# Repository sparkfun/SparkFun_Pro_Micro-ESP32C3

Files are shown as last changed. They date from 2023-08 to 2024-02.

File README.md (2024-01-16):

SparkFun Pro Micro ESP32-C3
========================================

SparkFun Pro Micro ESP32-C3 (https://www.sparkfun.com/products/23484)

[*SparkFun Pro Micro ESP32-C3 (DEV-23484)*](https://www.sparkfun.com/products/23484)

Don't be fooled by its miniature size; the SparkFun Pro Micro ESP32-C3 packs a punch. This micro marvel crams the powerful ESP32-C3, a single-core RISC-V powerhouse with 400KB of SRAM, into a compact 1.3in. x 0.7in. board. Clocking in at 160MHz, it's ready to tackle your projects quickly and efficiently.

Forget wires and soldering headaches – the Pro Micro ESP32-C3 embraces the simplicity of the Qwiic connector. Just plug and play any Qwiic sensor and watch your projects come alive with environmental data, motion detection, or whatever your imagination conjures. And stay connected, wherever you are, with built-in WiFi and Bluetooth® 5 (LE).

But the Pro Micro ESP32-C3 isn't just about small talk. Its 22 programmable GPIOs, accessible through handy castellated headers, unlock a multitude of possibilities. From tinkering with LEDs and servos to crafting intricate sensor networks, this tiny titan has the muscle to handle it all. And thanks to support for a range of protocols like ADC, SPI, UART, and I<sup>2</sup>C, the creative toolbox keeps expanding.

The Pro Micro ESP32-C3 taps into the power of Espressif's open-source ESP-IDF, a robust ecosystem brimming with libraries, tools, and a supportive community. Plus, you can leverage the familiar Arduino IDE for a smooth development experience.

So whether you're building a wearable masterpiece, a chatty IoT gadget, or a robotic friend, the SparkFun Pro Micro ESP32-C3 is your pint-sized partner in innovation. Grab one today and let your small-scale dreams take flight!

Repository Contents
-------------------

* **/Documentation** - Data sheets, additional product information
* **/Hardware** - Eagle design files (.brd, .sch)
* **/Production** - Production panel files (.brd)

Documentation
--------------
* **[Hookup Guide](https://docs.sparkfun.com/SparkFun_Pro_Micro-ESP32C3)** - Basic hookup guide for the SparkFun Pro Micro ESP32-C3

License Information
-------------------

This product is _**open source**_! 

Please review the LICENSE.md file for license information. 

If you have any questions or concerns on licensing, please contact technical support on our [SparkFun forums](https://forum.sparkfun.com/viewforum.php?f=152).

Distributed as-is; no warranty is given.

- Your friends at SparkFun.

_<COLLABORATION CREDIT>_

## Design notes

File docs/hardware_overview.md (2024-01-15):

---
icon: material/cog
---

## ESP32 C3 WiFi Module

The ESP32-C3 from Espressif is a single-core, 32-bit, RISC-V-based MCU with 400KB of SRAM, which is capable of running at 160MHz. It has integrated 2.4 GHz Wi-Fi and Bluetooth 5 (LE) with a long-range support. It has 22 programmable GPIOs with support for ADC, SPI, UART, I2C, I2S, RMT, TWAI, and PWM. More information is available in the [datasheet](Documents/esp32-c3-mini-1_datasheet_en.pdf). 

<figure markdown>
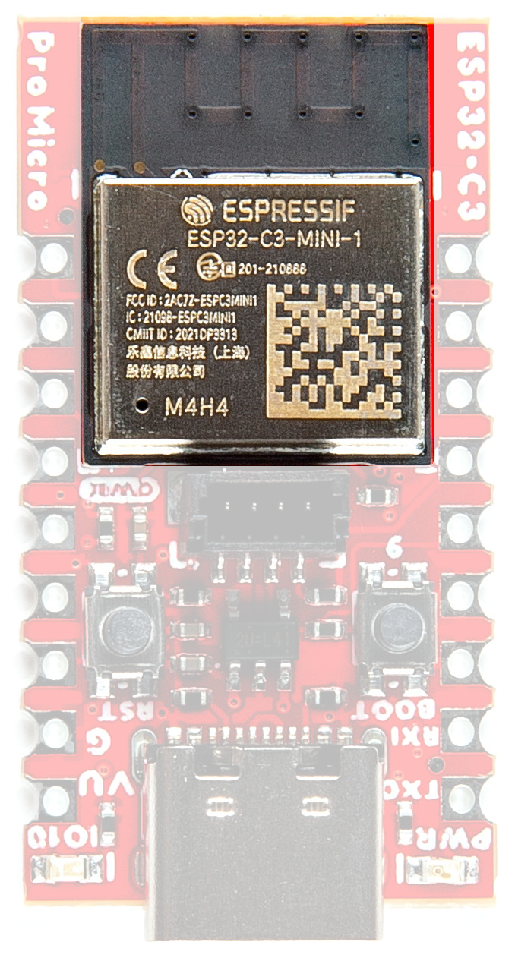
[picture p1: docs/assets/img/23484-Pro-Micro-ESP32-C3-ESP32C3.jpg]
ESP32 C3 WiFi Module

<figcaption markdown>ESP32 C3 WiFi Module</figcaption>
</figure>

## Voltage Regulator - RT9080

The RT9080 regulates voltage to the various components of the board. Maximum input voltage should be no more than <b>5.5V</b>. 

Current Max: 600mA

<figure markdown>
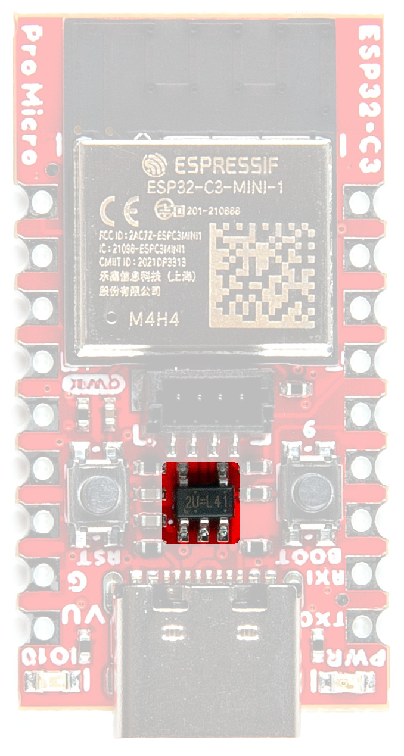
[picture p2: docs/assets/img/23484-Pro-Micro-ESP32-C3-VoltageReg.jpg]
Voltage Regulator - RT9080

<figcaption markdown>Voltage Regulator - RT9080</figcaption>
</figure>

## Qwiic Connector

The board includes a Qwiic connector for use with our vast array of Qwiic sensors. For users that need to solder directly to the board, the pins are also broken out on the edge PTH. The I<sup>2</sup>C data and clock lines are also tied to 2.2kΩ pull-up resistors.

<figure markdown>
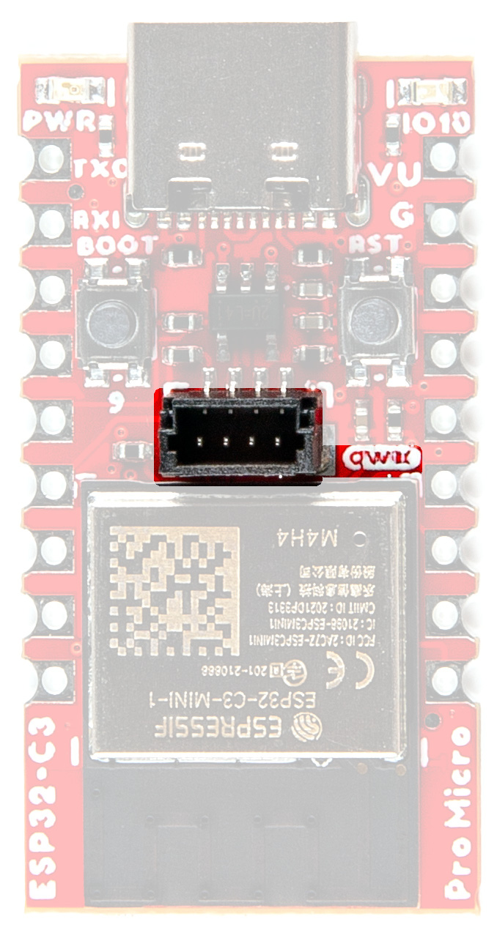
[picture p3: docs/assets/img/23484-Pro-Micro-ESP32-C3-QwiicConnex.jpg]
Qwiic Connector

<figcaption markdown>Qwiic Connector</figcaption>
</figure>

## JTAG 

While most users will utilize the USB connection for programming, the ESP32-C3 can also be programmed through its JTAG or SWD pins. This is useful for individuals developing and debugging firmware that would be flashed directly onto the module, such as in production for commercial applications. We recommend soldering a [2x5 Male Pin header](https://www.sparkfun.com/products/15362) for use. 

<figure markdown>
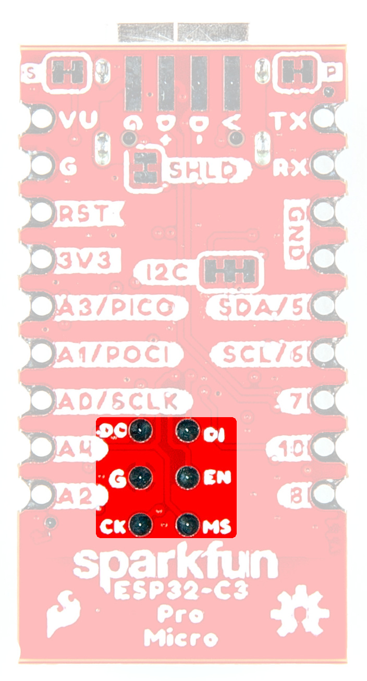
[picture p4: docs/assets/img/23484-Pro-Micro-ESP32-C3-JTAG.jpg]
ESP32 JTAG pads

<figcaption markdown>ESP32 JTAG pads</figcaption>
</figure>

## Castellated Headers

The castellated headers along either side of the board are useful for adding complex functionality like RF to a design, as well as being low profile and compact. If you've never worked with castellated headers, head on over to our [Castellated Mounting Holes Tutorial](https://learn.sparkfun.com/tutorials/how-to-solder-castellated-mounting-holes) for more information. 

<figure markdown>
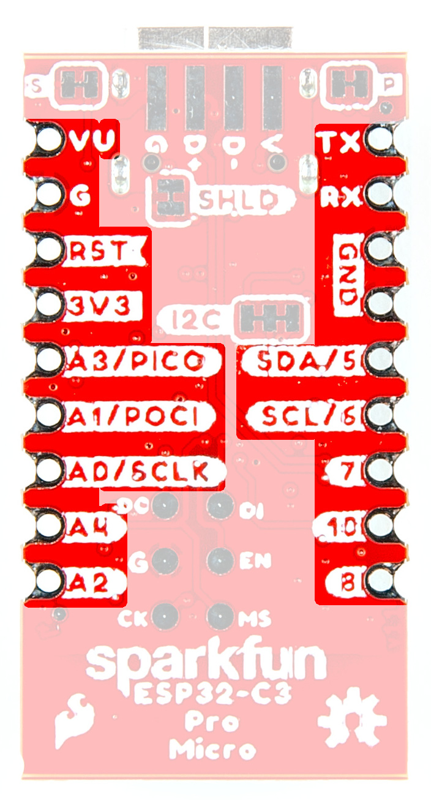
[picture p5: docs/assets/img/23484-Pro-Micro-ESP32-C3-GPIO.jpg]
ESP32 GPIO

<figcaption markdown>Castellated Headers</figcaption>
</figure>

## Buttons

There are two buttons on the board - Reset and Boot. The reset (RST) button allows users to reset the program running on the ESP32-C3 module without unplugging the board. The Boot Button allows the user to manually put the board into Bootloader Mode. To enter bootloader, hold the Boot button down when the ESP32 resets or powers on. 

<figure markdown>
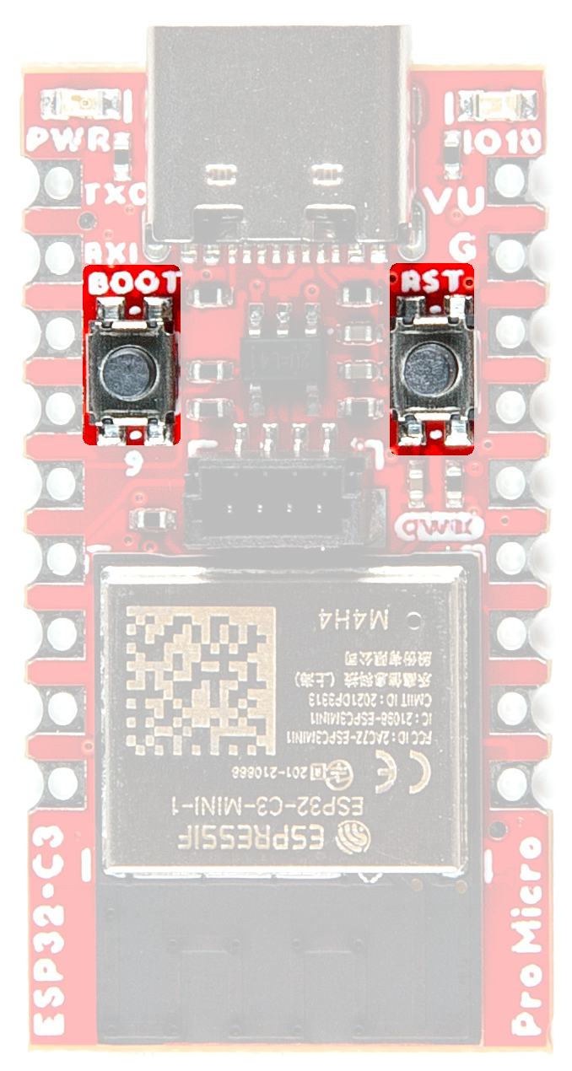
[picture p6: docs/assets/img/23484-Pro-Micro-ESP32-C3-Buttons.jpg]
ESP32 Boot and Reset Buttons

<figcaption markdown>Boot and Reset Buttons</figcaption>
</figure>

## LEDs

Two LEDs - Power(Red) and STAT(Blue) - show the user that power has been appropriately supplied to the board and the status of the data transfer. 

<figure markdown>
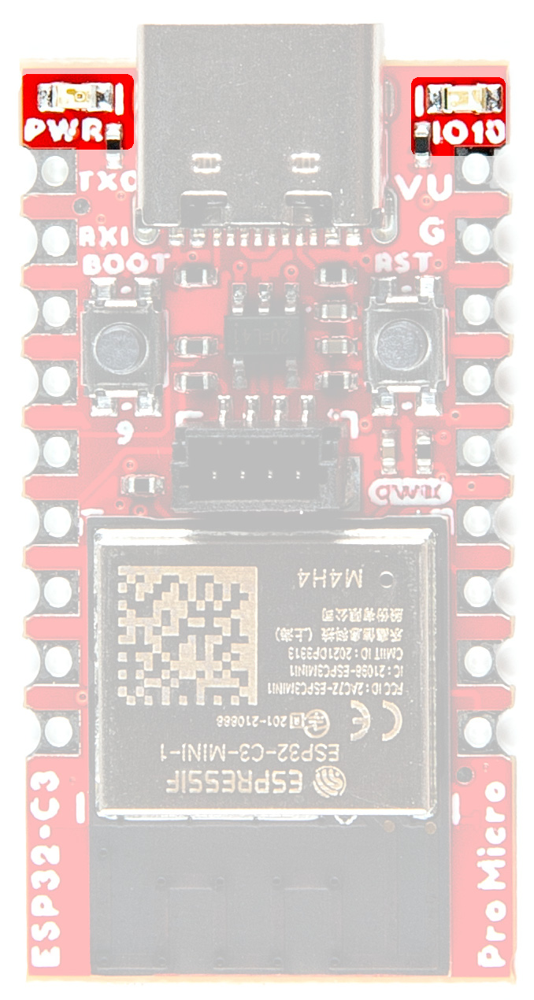
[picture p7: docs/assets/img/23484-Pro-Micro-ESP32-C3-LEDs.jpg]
Power and Status LEDs

<figcaption markdown>Power and Status LEDs</figcaption>
</figure>

## Jumpers

??? note "Never modified a jumper before?"
	Check out our <a href="https://learn.sparkfun.com/tutorials/664">Jumper Pads and PCB Traces tutorial</a> for a quick introduction!
	<p align="center">
		<a href="https://learn.sparkfun.com/tutorials/664">
		Tutorial's thumbnail<br>
        How to Work with Jumper Pads and PCB Traces</a>
	</p>

### I<sup>2</sup>C Jumper

If you choose to use one or more Qwiic breakouts in your project, it is important to note that this board comes equipped with pull-up resistors on the clock and data pins. If you are daisy-chaining multiple Qwiic devices, you will want to cut this jumper; if multiple sensors are connected to the bus with the pull-up resistors enabled, the parallel equivalent resistance will create too strong of a pull-up for the bus to operate correctly. As a general rule of thumb, disable all but one pair of pull-up resistors if multiple devices are connected to the bus. To disable the pull up resistors, use an X-acto knife to cut the joints between theWS jumper pads highlighted below.

<figure markdown>
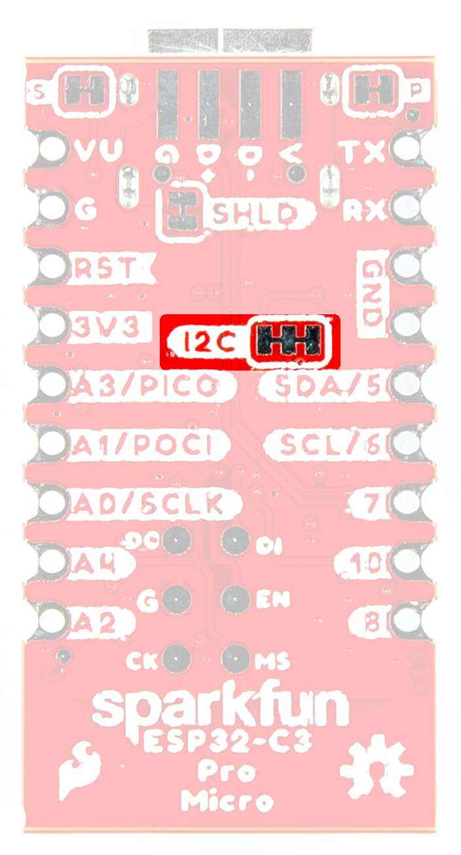
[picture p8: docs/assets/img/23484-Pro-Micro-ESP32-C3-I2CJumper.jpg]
I2C Jumpers

<figcaption markdown>I2C Jumpers</figcaption>
</figure>

### LED Jumpers

If power consumption is an issue or you wish to disable the LEDs on the front of the board, cut the trace between the jumpers shown here. 

<figure markdown>
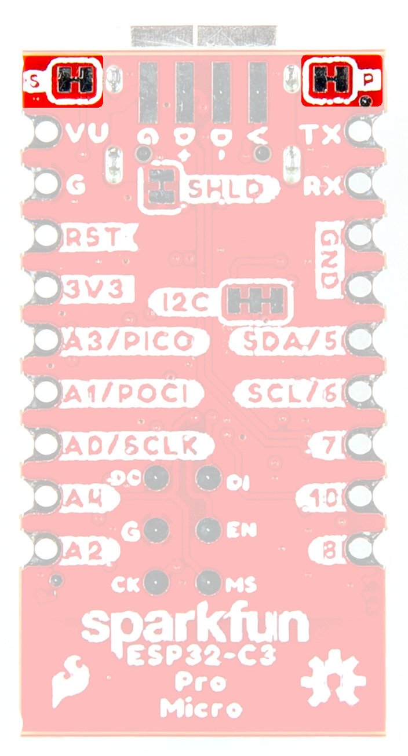
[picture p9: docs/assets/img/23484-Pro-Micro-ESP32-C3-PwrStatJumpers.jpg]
LED Jumpers

<figcaption markdown>LED Jumpers</figcaption>
</figure>

### Shield Jumper

For most applications, the single point grounding of the USB-C connector is sufficient. However, should you run into problems with EMI/EMC, we've provided a jumper that allow you to disconnect the USB Shield from ground.

<figure markdown>
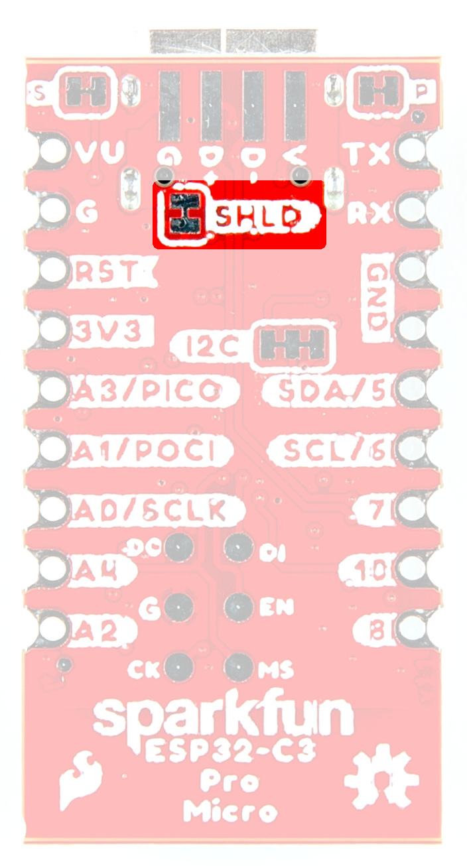
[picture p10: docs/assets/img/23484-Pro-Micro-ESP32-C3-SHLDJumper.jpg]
Shield Jumpers

<figcaption markdown>Shield Jumpers</figcaption>
</figure>

## Board Dimensions

The SparkFun ESP32-C3 Pro Micro measures 0.7" x 1.3". 

<figure markdown>
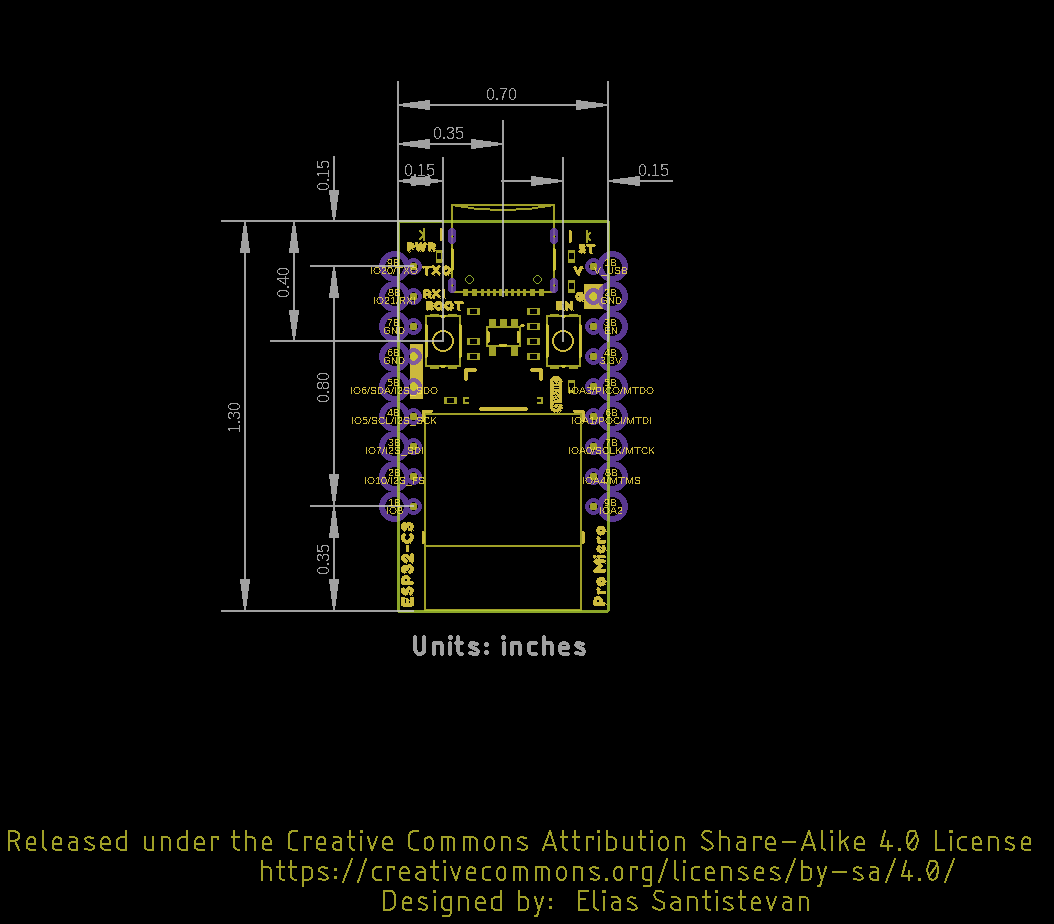
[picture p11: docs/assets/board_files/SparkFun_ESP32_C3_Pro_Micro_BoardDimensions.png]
SparkFun ESP32-C3 Pro Micro Board Outline

<figcaption markdown>SparkFun ESP32-C3 Pro Micro Board Outline</figcaption>
</figure>

??? tip "Need more measurements?"
	For more information about the board's dimensions, users can download the [Eagle files](assets/board_files/SparkFun_ESP32_C3_Pro_Micro_EagleFiles.zip). These files can be opened in Eagle and additional measurements can be made with the dimensions tool.

	??? info ":octicons-download-16:{ .heart } Eagle - Free Download!"
		Eagle is a [CAD]("computer-aided design") program for electronics that is free to use for hobbyists and students. However, it does require an account registration to utilize the software.

		<center>
		[Download from<br>:autodesk-primary:{ .autodesk }](https://www.autodesk.com/products/eagle/free-download "Go to downloads page"){ .md-button .md-button--primary width="250px" }
		</center>
	
	??? info ":straight_ruler: Dimensions Tool"
		This video from Autodesk demonstrates how to utilize the dimensions tool in Eagle, to include additional measurements:

		<center>
		<div class="video">
		<iframe src="https://www.youtube.com/embed/dZLNd1FtNB8" title="EAGLE Dimension Tool" frameborder="0" allow="accelerometer; autoplay; clipboard-write; encrypted-media; gyroscope; picture-in-picture" allowfullscreen></iframe>
		</div>
		</center>

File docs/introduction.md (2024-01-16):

---
icon: material/book-open-page-variant
---

## Introduction

<div class="grid cards desc" markdown>

-    <a href="https://www.sparkfun.com/products/23484">
    **SparkFun Pro Micro - ESP32-C3**<br>
    **SKU:** DEV-23484

    ---

    <figure markdown>
    Product Thumbnail
    </figure></a>

-    Don't be fooled by its miniature size; the SparkFun Pro Micro ESP32-C3 packs a punch. This micro marvel crams the powerful ESP32-C3, a single-core RISC-V powerhouse with 400KB of SRAM, into a compact 1.3in. x 0.7in. board. Clocking in at 160MHz, it's ready to tackle your projects quickly and efficiently. Forget wires and soldering headaches – the Pro Micro ESP32-C3 embraces the simplicity of the Qwiic connector. Just plug and play any Qwiic sensor and watch your projects come alive with environmental data, motion detection, or whatever your imagination conjures. And stay connected, wherever you are, with built-in WiFi and Bluetooth® 5 (LE).

    <center>
    [Purchase from SparkFun :fontawesome-solid-cart-plus:{ .heart }](https://www.sparkfun.com/products/23484){ .md-button .md-button--primary }
    </center>

</div>

## Required Materials
To get started, users will need a few items. You may already have a few of these items, feel free to modify your cart accordingly.

<div class="grid cards hide col-4" markdown>

-   <a href="https://www.sparkfun.com/products/23484">
    <figure markdown>
    Product Thumbnail
    </figure>

    ---

    **SparkFun Pro Micro - ESP32-C3**<br>
    DEV-23484</a>

-   <a href="https://www.sparkfun.com/products/15425">
    <figure markdown>
    Product Thumbnail
    </figure>

    ---

    **Reversible USB A to C Cable - 0.8m**<br>
    CAB-15425</a>

</div>

## Suggested Reading

If you aren’t familiar with the following concepts, we recommend checking out these tutorials before continuing.

<div class="grid cards hide col-4" markdown align="center">

-   <a href="https://learn.sparkfun.com/tutorials/82">
    <figure markdown>
    I2C
    </figure>
    </a>
    <a href="https://learn.sparkfun.com/tutorials/82">**I2C**
    </a>

-   <a href="https://learn.sparkfun.com/tutorials/analog-vs-digital">
    <figure markdown>
    Analog vs. Digital
    </figure>
    </a>
    <a href="https://learn.sparkfun.com/tutorials/analog-vs-digital">**Analog vs. Digital**
    </a>

-   <a href="https://learn.sparkfun.com/tutorials/serial-peripheral-interface-spi">
    <figure markdown>
    SPI
    </figure>
    </a>
    <a href="https://learn.sparkfun.com/tutorials/serial-peripheral-interface-spi">**SPI**
    </a>
</div>

<center>
<div align="center">
    <div style="top:5px;left:5px;background-color:Gray;position:relative">
        <div style="top:-5px;left:-5px;background-color:#ffffff;position:relative;border:1px solid black;">
            <a href="https://www.sparkfun.com/qwiic">Qwiic Connect System</a>
        </div>
    </div>
</div>
</center>

The SparkFun Pro Micro ESP32-C3 takes advantage of the [Qwiic connect system](https://www.sparkfun.com/qwiic). We recommend familiarizing yourself with the **Logic Levels** and **I<sup>2</sup>C** tutorials.  Click on the banner above to learn more about [Qwiic products](https://www.sparkfun.com/qwiic).

<center>
    <iframe width="600" height="327" src="https://www.youtube.com/embed/x0RDEHqFIF8" title="SparkFun's Qwiic Connect System" frameborder="0" allow="accelerometer; autoplay; clipboard-write; encrypted-media; gyroscope; picture-in-picture" allowfullscreen></iframe>
</center>

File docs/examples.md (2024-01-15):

---
icon: simple/arduino
---

Now that we've installed the espressif boards package in Arduino, it's time to upload our first sketch to make sure everything is working properly.

## Example 1 - Blink 

This basic example makes sure the board package installed correctly and the board accepts programming properly to blink the blue IO10 LED on the board every second. Open the example in Arduino by navigating to File > Examples > Basics > 01-Blink.

You will need to define LED_BUILTIN as 10 like so: 

<figure markdown>
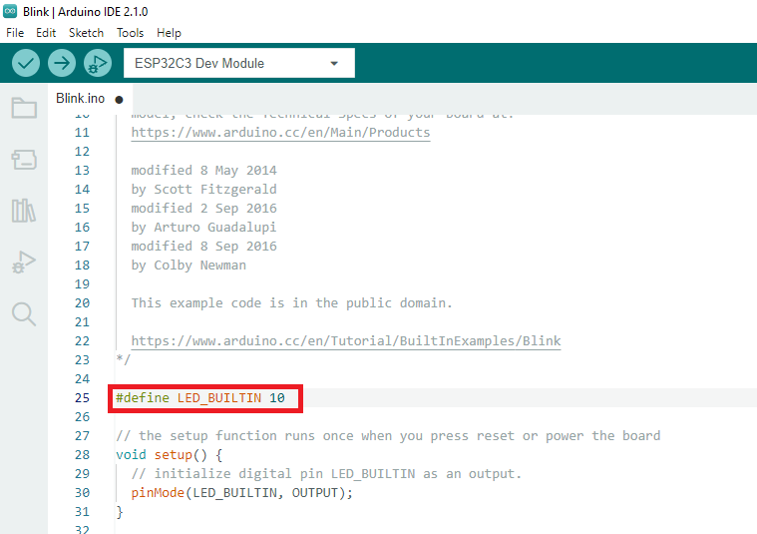
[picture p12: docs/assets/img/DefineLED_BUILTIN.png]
LED Builtin is Defined

<figcaption markdown>Code changes for LED_BUILTIN</figcaption>
</figure>

Make sure you have the board and port selected like so: 

<figure markdown>
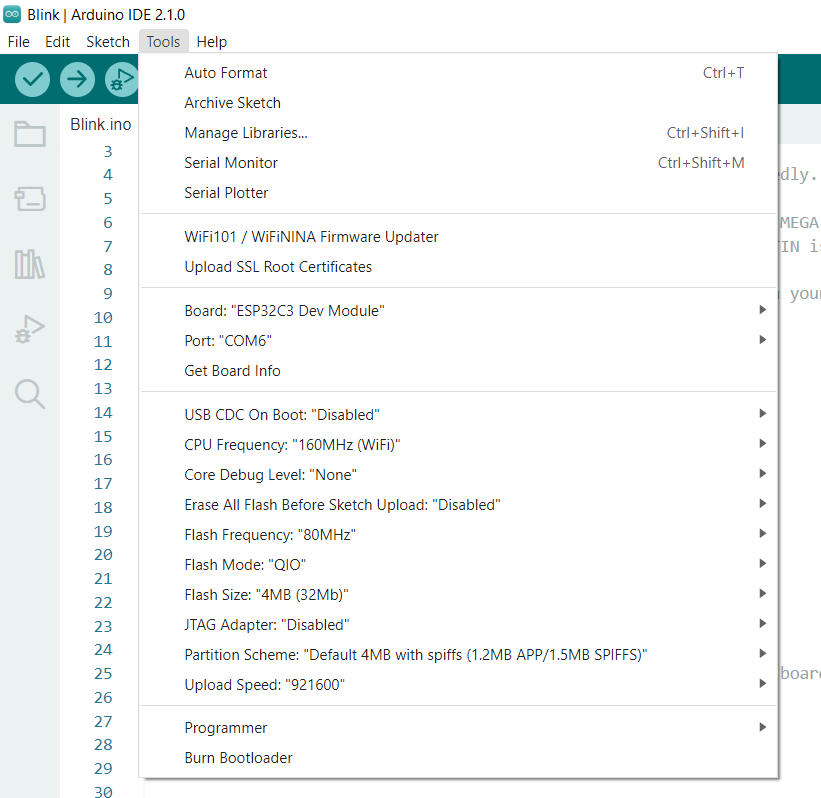
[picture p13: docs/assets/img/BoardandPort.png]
Board and Port selected

<figcaption markdown>Board and Port selected</figcaption>
</figure>

### Uploading Code

Before uploading, you'll need to put the board into the <a href="https://docs.espressif.com/projects/esptool/en/latest/esp32/advanced-topics/boot-mode-selection.html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">serial bootloader</a> with the <kbd>BOOT</kbd> button. Holding down the <kbd>BOOT</kbd> button, while connecting the board to a computer through its USB-C connector or resetting the board will cause the MCU to enter the <a href="https://docs.espressif.com/projects/esptool/en/latest/esp32/advanced-topics/boot-mode-selection.html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">Firmware Download mode</a> and its serial bootloader. The board will remain in this mode until it power cycles (happens automatically after uploading new firmware) or the <kbd>RST</kbd> button is pressed.

1. Hold the <kbd>BOOT</kbd> button down.
2. Reset the MCU.
    * While unpowered, connect the board to a computer with through the USB-C connection.
    * While powered, press the <kbd>RST</kbd> button.
3. Release the <kbd>BOOT</kbd> button.
4. After programming is completed, reboot the MCU.
    * Press the <kbd>RST</kbd> button.
    * Power cycle the board. 

Once the board is in the serial bootloader, you can upload code through the Arduino interface. Once your code is uploaded, you will need to hit the <kbd>RST</kbd> button to get your sketch running. 

<figure markdown>
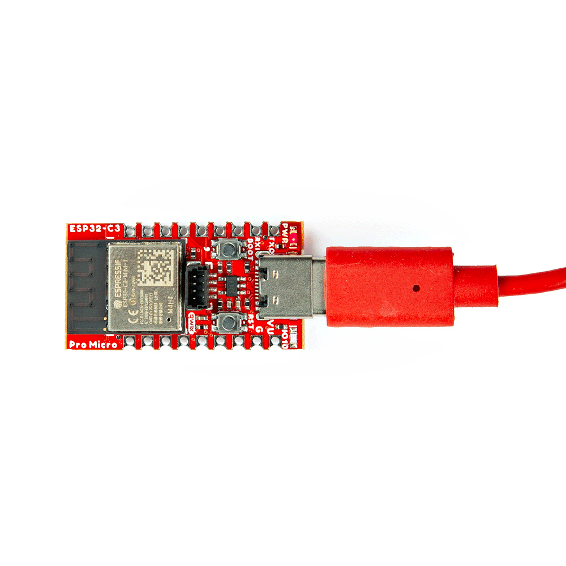
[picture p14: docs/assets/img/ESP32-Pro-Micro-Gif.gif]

<figcaption markdown>*blink blink blink*</figcaption>
</figure>

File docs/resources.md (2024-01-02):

<!-- This section should include all the relevant documentation and product files (Eagle files, schematic, datasheet(s), landing pages, etc. and any relevant tutorials to go beyond the Hookup Guide.) -->

For more resources related to the SparkFun ESP32-C3 Pro Micro, check out the links listed here: 

* [Product Page](https://www.sparkfun.com/products/23484)
* [Schematic](assets/board_files/SparkFun_ESP32_C3_Pro_Micro_Schematic.pdf) (PDF)
* [Eagle Files](assets/board_files/SparkFun_ESP32_C3_Pro_Micro_EagleFiles.zip) (ZIP)
* [Board Dimensions](assets/board_files/SparkFun_ESP32_C3_Pro_Micro_BoardDimensions.png) (PDF)
* [GitHub Repository](https://github.com/sparkfun/SparkFun_Pro_Micro-ESP32C3)

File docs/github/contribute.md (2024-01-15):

# Contribute: Make an Augmentation!
Spot an improvement opportunity? Feel free to contribute to our open-source design and documentation. 

## :material-file-document-multiple:&nbsp;Improve our Documentation
All of this documentation can be modified by you! Please help us make it better.

* These pages are contained in the [`docs` folder](https://github.com/sparkfun/SparkFun_Pro_Micro-ESP32C3/tree/main/docs) of the [SparkFun Pro Micro ESP32-C3 repository](https://github.com/sparkfun/SparkFun_Pro_Micro-ESP32C3).

<!-- ### :material-source-pull:&nbsp;Submit a Correction -->
### Submit a Correction

1. With a GitHub account, [fork this repository](https://github.com/sparkfun/SparkFun_Pro_Micro-ESP32C3/fork).
2. Add your corrections or improvements to the markdown file.
3. File a pull request with your changes, and enjoy making the ~~words~~ ~~worlds~~ world a better place.
	* Once received, the documentation specialist will automatically be notified.
	* We will review your suggested improvements to make sure they are correct and fit within our documentation standards.

## :material-cog:&nbsp;Improve our Hardware Design
All of our designs are open-source! Please help us make it better.

* Our board design files are contained in the [`Hardware` folder](https://github.com/sparkfun/SparkFun_Pro_Micro-ESP32C3/tree/main/Hardware) of the [SparkFun Pro Micro ESP32-C3 repository](https://github.com/sparkfun/SparkFun_Pro_Micro-ESP32C3).

<!-- ### :material-source-pull:&nbsp;Submit a Design Enhancement -->
### Submit a Design Enhancement

1. With a GitHub account, [fork this repository](https://github.com/sparkfun/SparkFun_Pro_Micro-ESP32C3/fork).
2. Add your design augmentation(s)
3. File a pull request with your changes, and enjoy making the ~~words~~ ~~worlds~~ world a better place.
	1. Once received, the engineer in charge of the original design will automatically be notified.
	2. We will review your suggested improvement(s) to verify that they are within our board design standards and meet our product design requirements.
	3. If approved, we will flag these changes for our next board revision. Congrats! 🍻

		!!! info
			Even if your suggestion is accepted, these changes may not be immediately available for purchase. We may have to cycle through our current product inventory first.

## Contributors&nbsp;:clap:
Let's provide some recognition to the contributors for this project!

GitHub Contributors Image
<br>


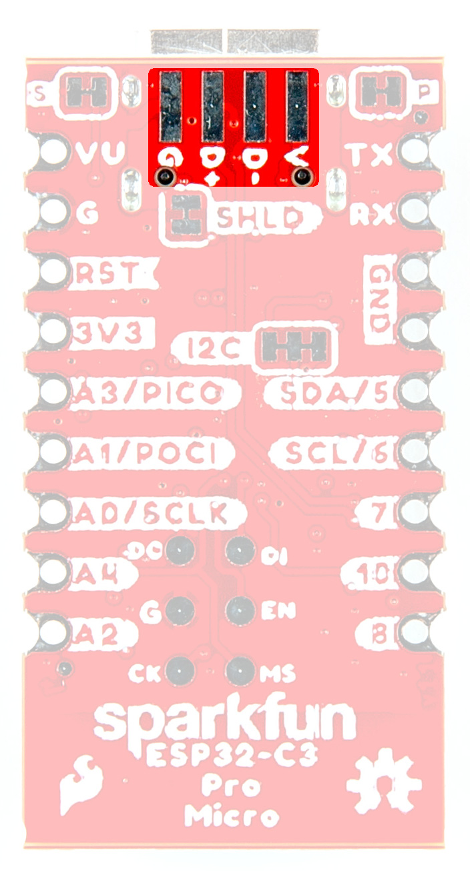
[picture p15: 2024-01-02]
docs/assets/img/23484-Pro-Micro-ESP32-C3-USBPads.jpg

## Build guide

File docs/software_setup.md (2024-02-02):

---
icon: simple/arduino
---

!!! arduino

    ### Arduino IDE

    This example assumes you are using the latest version of the Arduino IDE on your desktop. If this is your first time using Arduino IDE and an library, please review the following tutorials.

    - [Installing the Arduino IDE](https://learn.sparkfun.com/tutorials/installing-arduino-ide)
    - [Installing an Arduino Library](https://learn.sparkfun.com/tutorials/installing-an-arduino-library)

    ### USB-to-Serial Drivers

    If you've never connected an CH340 device to your computer before, you may need to install drivers for the USB-to-serial converter. Check out our section on "[How to Install CH340 Drivers](https://learn.sparkfun.com/tutorials/sparkfun-serial-basic-ch340c-hookup-guide#drivers-if-you-need-them)" for help with the installation.

## Installation (Windows)

The SparkFun Pro Micro - ESP32-C3 board files are waiting on an official release from the Espressif Arduino Core. In the meantime you can add the board files manually. There is a file included in the [SparkFun_Pro_Micro-ESP32C3 Github Repository](https://github.com/sparkfun/SparkFun_Pro_Micro-ESP32C3/tree/main/Arduino_Board_Files) titled "Arduino_Board_Files", which contains a "Variant" folder labeled "sparkfun_pro_micro_esp32c3" and a "sparkfun_boards.txt" file. The variant file will need to be placed locaally into your machine and the contents of the "sparkfun_boards.txt" will need to be copied into the local "boards.txt" file.

All of the Espressif Arduino Core files on your local computer can be found here on a Windows 10 machine: 

    C:\Users\<USERNAME>\AppData\Local\Arduino15\packages\esp32\hardware\esp32 

Make sure you change USERNAME to your name! 

You'll see a folder located here with some version number depending on what you have installed. Within that folder there are directores that look like the following:

<figure markdown>
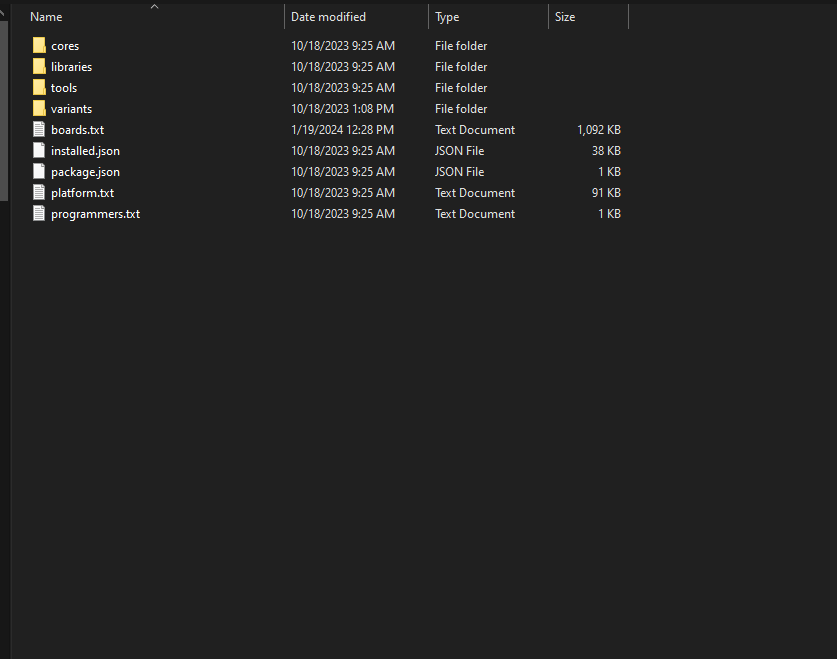
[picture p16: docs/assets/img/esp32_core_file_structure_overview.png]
Core Files

<figcaption markdown>Core Files</figcaption>
</figure>

Here is where we'll "install" the files for the SparkFun Pro Micro ESP32-C3. First you'll take the variant folder named "sparkfun_pro_micro_esp32c3" and drag and drop it within the "variants" folder on your local machine.

From: 

<figure markdown>
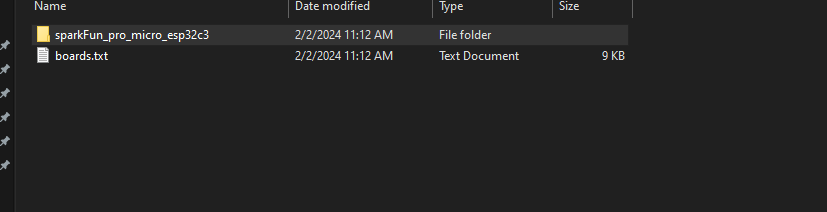
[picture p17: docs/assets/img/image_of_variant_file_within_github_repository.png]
SparkFun Variant file within Github Repository

<figcaption markdown>SparkFun Variant file within Github Repository</figcaption>
</figure>

To: 

<figure markdown>
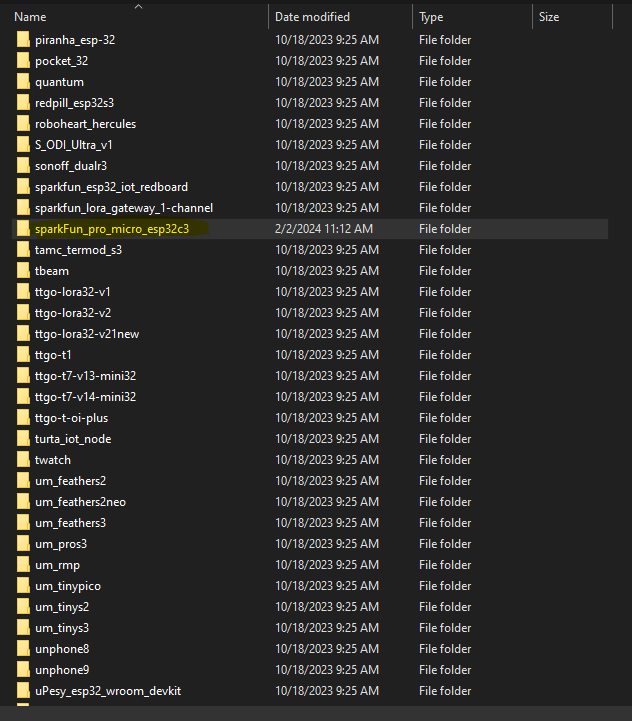
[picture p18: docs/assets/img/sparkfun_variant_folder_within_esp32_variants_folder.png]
SparkFun Variant file within ESP32 Variants File

<figcaption markdown>SparkFun Variant file within ESP32 Variants File</figcaption>
</figure>

We're almost there. Next we're going to copy the text WITHIN the "sparkfun_boards.txt" found in the Github Repository and paste it into the "boards.txt" file within the Espressif Arduino Core on your local computer. First open the both the "boards.txt" file from you local machine and the "sparkfun_boards.txt". Now copy the entire text from the "sparkfun_boards.txt" file to the END of the "boards.txt" file.

<figure markdown>
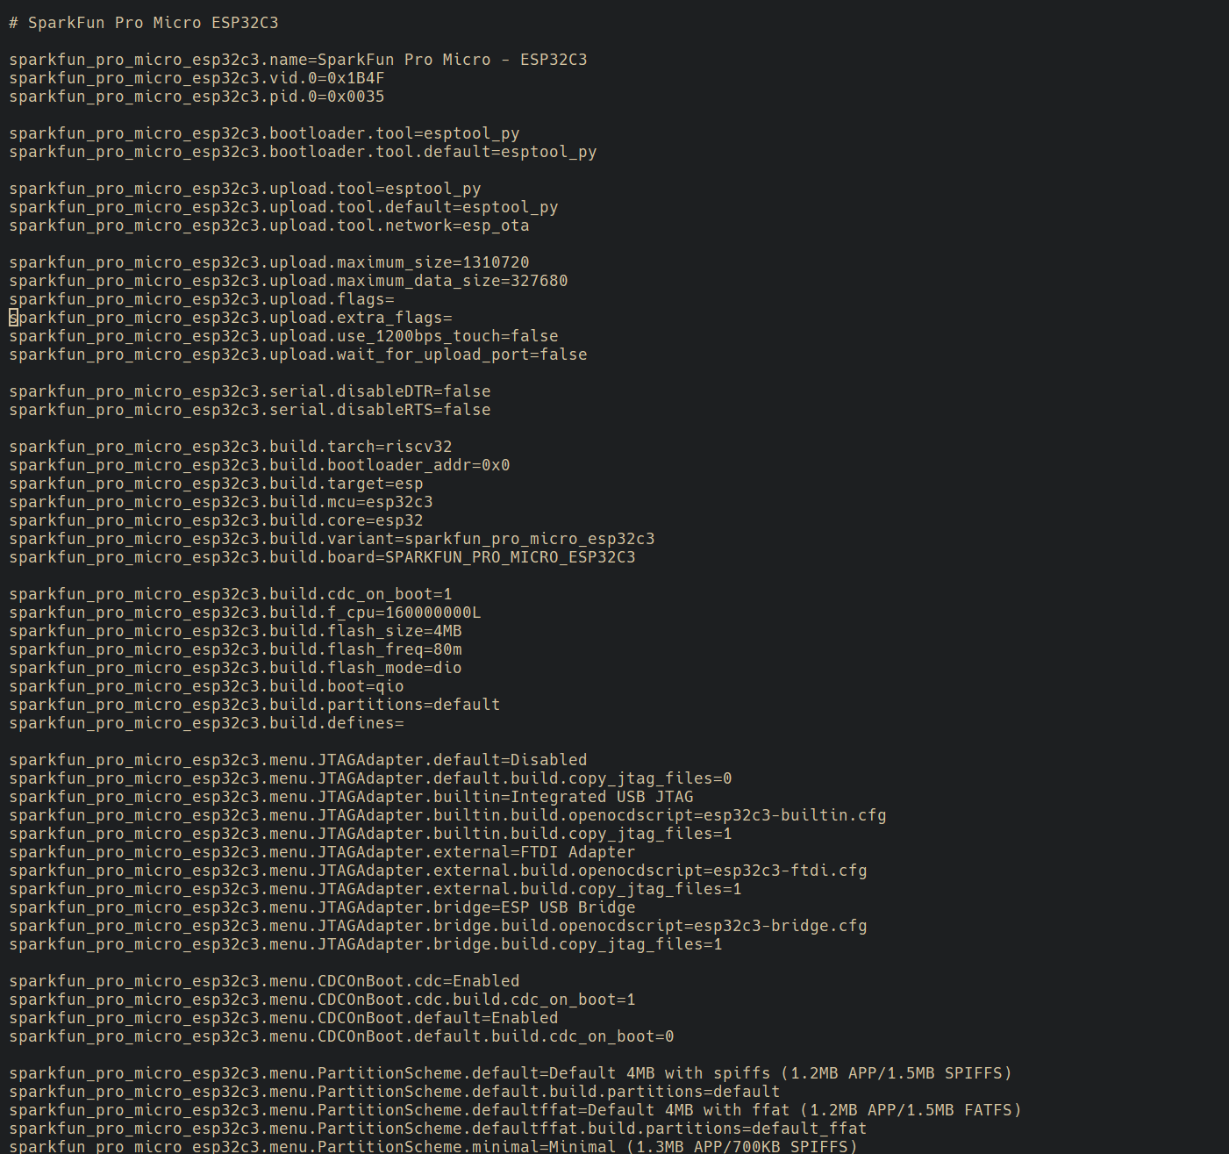
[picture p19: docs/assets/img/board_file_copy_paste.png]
Boards File

<figcaption markdown>Boards File</figcaption>
</figure>

That's it. Now when you go to open the Arduino IDE and navigate to the esp32 core within the boards options you should see it show up there. 

<figure markdown>
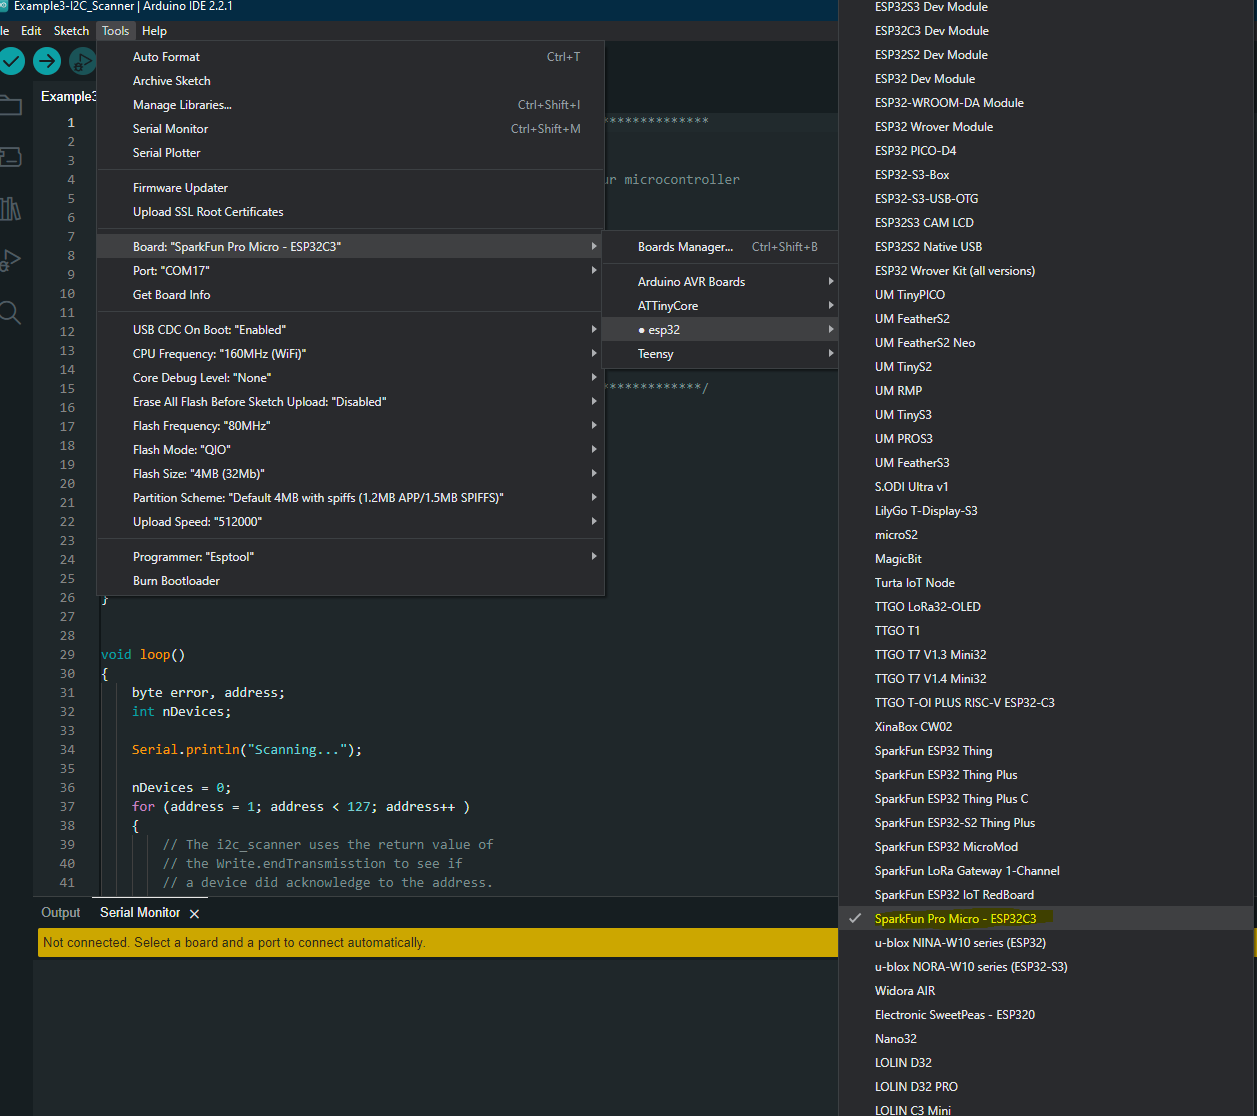
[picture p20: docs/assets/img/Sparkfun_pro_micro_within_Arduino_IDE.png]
SparkFun Pro Micro in Arduino IDE

<figcaption markdown>SparkFun Pro Micro in Arduino IDE</figcaption>
</figure>

<!--

#### Install Board Definition
Install the latest <b>ESP32</b> board definitions in the Arduino IDE.

<div class="alert alert-info">
    <p><b>Note:</b> For more instructions, users can follow this tutorial on <a href="https://docs.arduino.cc/learn/starting-guide/cores">Installing Additional Cores</a> provided by Arduino. Users will also need the <code>.json</code> file for the Espressif Arduino core:</p>
    
    <p><center>
        <a href="https://raw.githubusercontent.com/espressif/arduino-esp32/gh-pages/package_esp32_index.json"><code>https://raw.githubusercontent.com/espressif/arduino-esp32/gh-pages/package_esp32_index.json</code></a>
    </center></p>
</div>
-->
<!--When selecting a board to program in the Arduino IDE, users should select the **SparkFun ESP32 Thing Plus C** from the Tools drop down menu *(i.e. **Tools** > **Board** > **ESP32 Arduino** > **SparkFun ESP32 Thing Plus C**)*. Alternatively, users can also select the **ESP32 Dev Module**; however, they may loose some pin assignments (i.e. `LED_BUILTIN`).

-> [![Board Selection](https://cdn.sparkfun.com/r/600-600/assets/learn_tutorials/2/3/5/3/board_selection.png)](https://cdn.sparkfun.com/assets/learn_tutorials/2/3/5/3/board_selection.png) <-
-> *Selecting the **SparkFun ESP32 Thing Plus C** from the Tools drop down menu in the Arduino IDE. (Click to enlarge)* <-

<div class="alert alert-info">
    <p><b>Note:</b> In the Arduino 2.0.x IDE users can also select the board from the <code>Select Board</code> drop down menu and search for the <b>SparkFun ESP32 Thing Plus C</b>:</p>
    
    <p><center>
        <a href="https://cdn.sparkfun.com/assets/learn_tutorials/2/3/5/3/arduino2-board_selection.png"><img alt="Arduino 2.0.x" src="https://cdn.sparkfun.com/r/500-500/assets/learn_tutorials/2/3/5/3/arduino2-board_selection.png"></a>
        <br>
        <i>Selecting the <b>SparkFun ESP32 Thing Plus C</b> in the Arduino 2.0.x IDE. (Click to enlarge)</i> 
    </center></p>
</div>

-->

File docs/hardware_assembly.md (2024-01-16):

---
icon: material/tools
---

The SparkFun Pro Micro ESP32-C3 could be considered "plug and play", depending on the project. If you want to use any of the I/O pins, however, you'll need to solder something to the board. If you've never worked with castellated headers,we recommend checking out our [Castellated Mounting Holes Tutorial](https://learn.sparkfun.com/tutorials/how-to-solder-castellated-mounting-holes) for more information.

??? note "New to soldering?"
	If you have never soldered before or need a quick refresher, check out our [How to Solder: Through-Hole Soldering](https://learn.sparkfun.com/tutorials/how-to-solder-through-hole-soldering) guide.

	<div class="grid cards col-4" markdown  align="center">

	-   <a href="https://learn.sparkfun.com/tutorials/5">
		<figure markdown>
		Tutorial thumbnail
		</figure>

		---
		
		**How to Solder: Through-Hole Soldering**</a>

	</div>

<figure markdown>
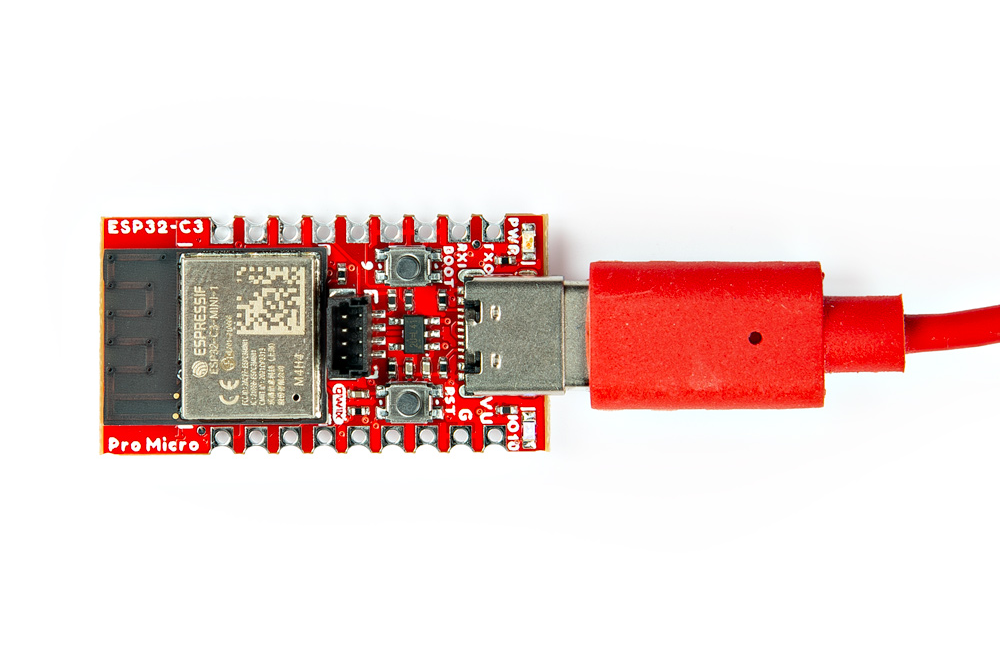
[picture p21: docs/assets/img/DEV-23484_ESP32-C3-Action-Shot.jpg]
ESP32 Connected to Programming

<figcaption markdown>SparkFun Pro Micro ESP32-C3 Connected to Programming</figcaption>
</figure>

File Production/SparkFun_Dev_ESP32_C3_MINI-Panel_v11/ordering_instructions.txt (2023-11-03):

panel size, 201x138mm
PCB thickness, 0.8mm
number of layers, 4
controlled impedance, JLC7628
soldermask color, Red
silkscreen color, White
oz copper, 1oz
finish, HASL lead free
stencils, none
pcs per panel, 24
min trace width, 0.1524mm / 0.0060in
min drill size, 0.3048mm / 0.0120in
filename to layer stackup 1/2/3/4: GTL, GL2, GL3, GBL

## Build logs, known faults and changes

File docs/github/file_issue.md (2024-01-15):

# Did we make a mistake?

Spot something wrong? Please let us know. 

<!-- Technical Assistance Box -->
!!! warning "Need Help?"
    If you need technical assistance or more information on a product that is not working as you expected, we recommend heading on over to the [SparkFun Technical Assistance](https://www.sparkfun.com/technical_assistanc) page for some initial troubleshooting. This **Submit Issues** page is not where users should seek assistance.

    <center>
    [SparkFun Technical Assistance Page](https://www.sparkfun.com/technical_assistance){ .md-button .md-button--primary }
    </center>
    
    If you can't find what you need there, the [SparkFun Forums](https://forum.sparkfun.com/index.php) is a great place to search the product forums and ask questions.
    
    !!! info "Account Registration Required"
        For your first visit to our forum, you'll need to create a [Forum Account](https://forum.sparkfun.com/ucp.php?mode=register) to post questions.

## Discrepancies in the Documentation

All of our documentation can be modified by you! Please help us make it better.

* The documentation files for these pages are contained in the [`docs` folder](https://github.com/sparkfun/SparkFun_Pro_Micro-ESP32C3/tree/main/docs) of the [SparkFun Pro Micro ESP32-C3 repository](https://github.com/sparkfun/SparkFun_Pro_Micro-ESP32C3).

### 🔍 Spot something wrong?

If a section of the documentation is incorrect, please [open an issue](https://github.com/sparkfun/SparkFun_Pro_Micro-ESP32C3/issues) and let us know.

### Do you have a suggested correction?

1. With a GitHub account, [fork this repository](https://github.com/sparkfun/SparkFun_Pro_Micro-ESP32C3/fork).
2. Add your correction(s) or improvement(s) to the markdown file(s)
3. File a pull request with your changes, and enjoy making the ~~words~~ ~~worlds~~ world a better place.
	* Once received, the documentation specialist will automatically be notified.
	* We will review your suggested improvement(s) to make sure they are correct and fit within our documentation standards.

## Problems in the Hardware Design

All of our designs are open-source! Please help us make it better.

* Our board design files are contained in the [`Hardware` folder](https://github.com/sparkfun/SparkFun_Pro_Micro-ESP32C3/tree/main/Hardware) of the [SparkFun Pro Micro ESP32-C3 repository](https://github.com/sparkfun/SparkFun_Pro_Micro-ESP32C3).

### Does something not make sense? 🤔

If part of the design is confusing, please [open an issue](https://github.com/sparkfun/SparkFun_Pro_Micro-ESP32C3/issues) and let us know.

### Did we forget to include an important function of the board? 🤦

If part of the board's functionality is missing, please [open an issue](https://github.com/sparkfun/SparkFun_Pro_Micro-ESP32C3/issues) and file a feature request.

!!! tip "Design Considerations"
	Please keep in mind that we may intentionally exclude certain functions of the board to meet our product design requirements.
	
	* *For example, our Qwiic Micro boards are intended to fit on a small board layout and only use I<sup>2</sup>C communication; therefore, we may not have the SPI and interrupt pins available for users.*

### Do you wish to contribute directly to improving the board design?

1. With a GitHub account, [fork this repository](https://github.com/sparkfun/SparkFun_Pro_Micro-ESP32C3/fork).
2. Add your design augmentation(s)
3. File a pull request with your changes, and enjoy making the ~~words~~ ~~worlds~~ world a better place.
	1. Once received, the engineer in charge of the original design will automatically be notified.
	2. We will review your suggested improvement(s) to verify that they are within our board design standards and meet our product design requirements.
	3. If approved, we will flag these changes for our next board revision. Congrats! 🍻

		!!! info
			Even if your suggestion is accepted, these changes may not be immediately available for purchase. We may have to cycle through our current product inventory first.

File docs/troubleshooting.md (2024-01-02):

---
icon: fontawesome/solid/question
---

!!! info
    <p><span class="glyphicon glyphicon-question-sign" aria-hidden="true"></span> <strong>Not working as expected and need help? </strong></p>
    <p>If you need technical assistance and more information on a product that is not working as you expected, we recommend heading on over to the <a href="https://www.sparkfun.com/technical_assistance">SparkFun Technical Assistance</a> page for some initial troubleshooting.</p>
    <center>
    [SparkFun Technical Assistance Page](https://www.sparkfun.com/technical_assistance){ .md-button .md-button--primary }
    </center>
    <p>If you can't find what you need there, you'll need a <a href="https://forum.sparkfun.com/ucp.php?mode=register">Forum Account</a> to search product forums and post questions.<p>

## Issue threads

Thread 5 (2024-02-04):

Build issue under Linux- folder name

brunofletcher, 2024-02-04:
Good evening. The build fails on case-sensitive operating system, such as Linux when using the Arduino IDE.

The following variable defined in "sparkfun_boards.txt":

sparkfun_pro_micro_esp32c3.build.variant=sparkfun_pro_micro_esp32c3

Needs to be changed to:

sparkfun_pro_micro_esp32c3.build.variant=sparkFun_pro_micro_esp32c3

if we use your current directory structure.

Note that a directory named "sparkfun_pro_micro_esp32c3" is not the same as "sparkFun_pro_micro_esp32c3" for case-sensitive operating systems.

Another possible solution is to just need to rename the directory from sparkFun_pro_micro_esp32c3 (containing "pins_arduino.h") to sparkfun_pro_micro_esp32c3 (i.e., all lower case).

Cheers,
Bruno

edspark, 2024-02-05:
Good morning,

Over the years I've developed some muscle memory when typing SparkFun. That's not intended to be camel case, and it's now been fixed.

Elias

Closed 2024-02-05.

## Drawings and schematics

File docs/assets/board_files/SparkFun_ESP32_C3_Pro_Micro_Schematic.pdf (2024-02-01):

# VBUS CC1 D+D- CC2 SHLD

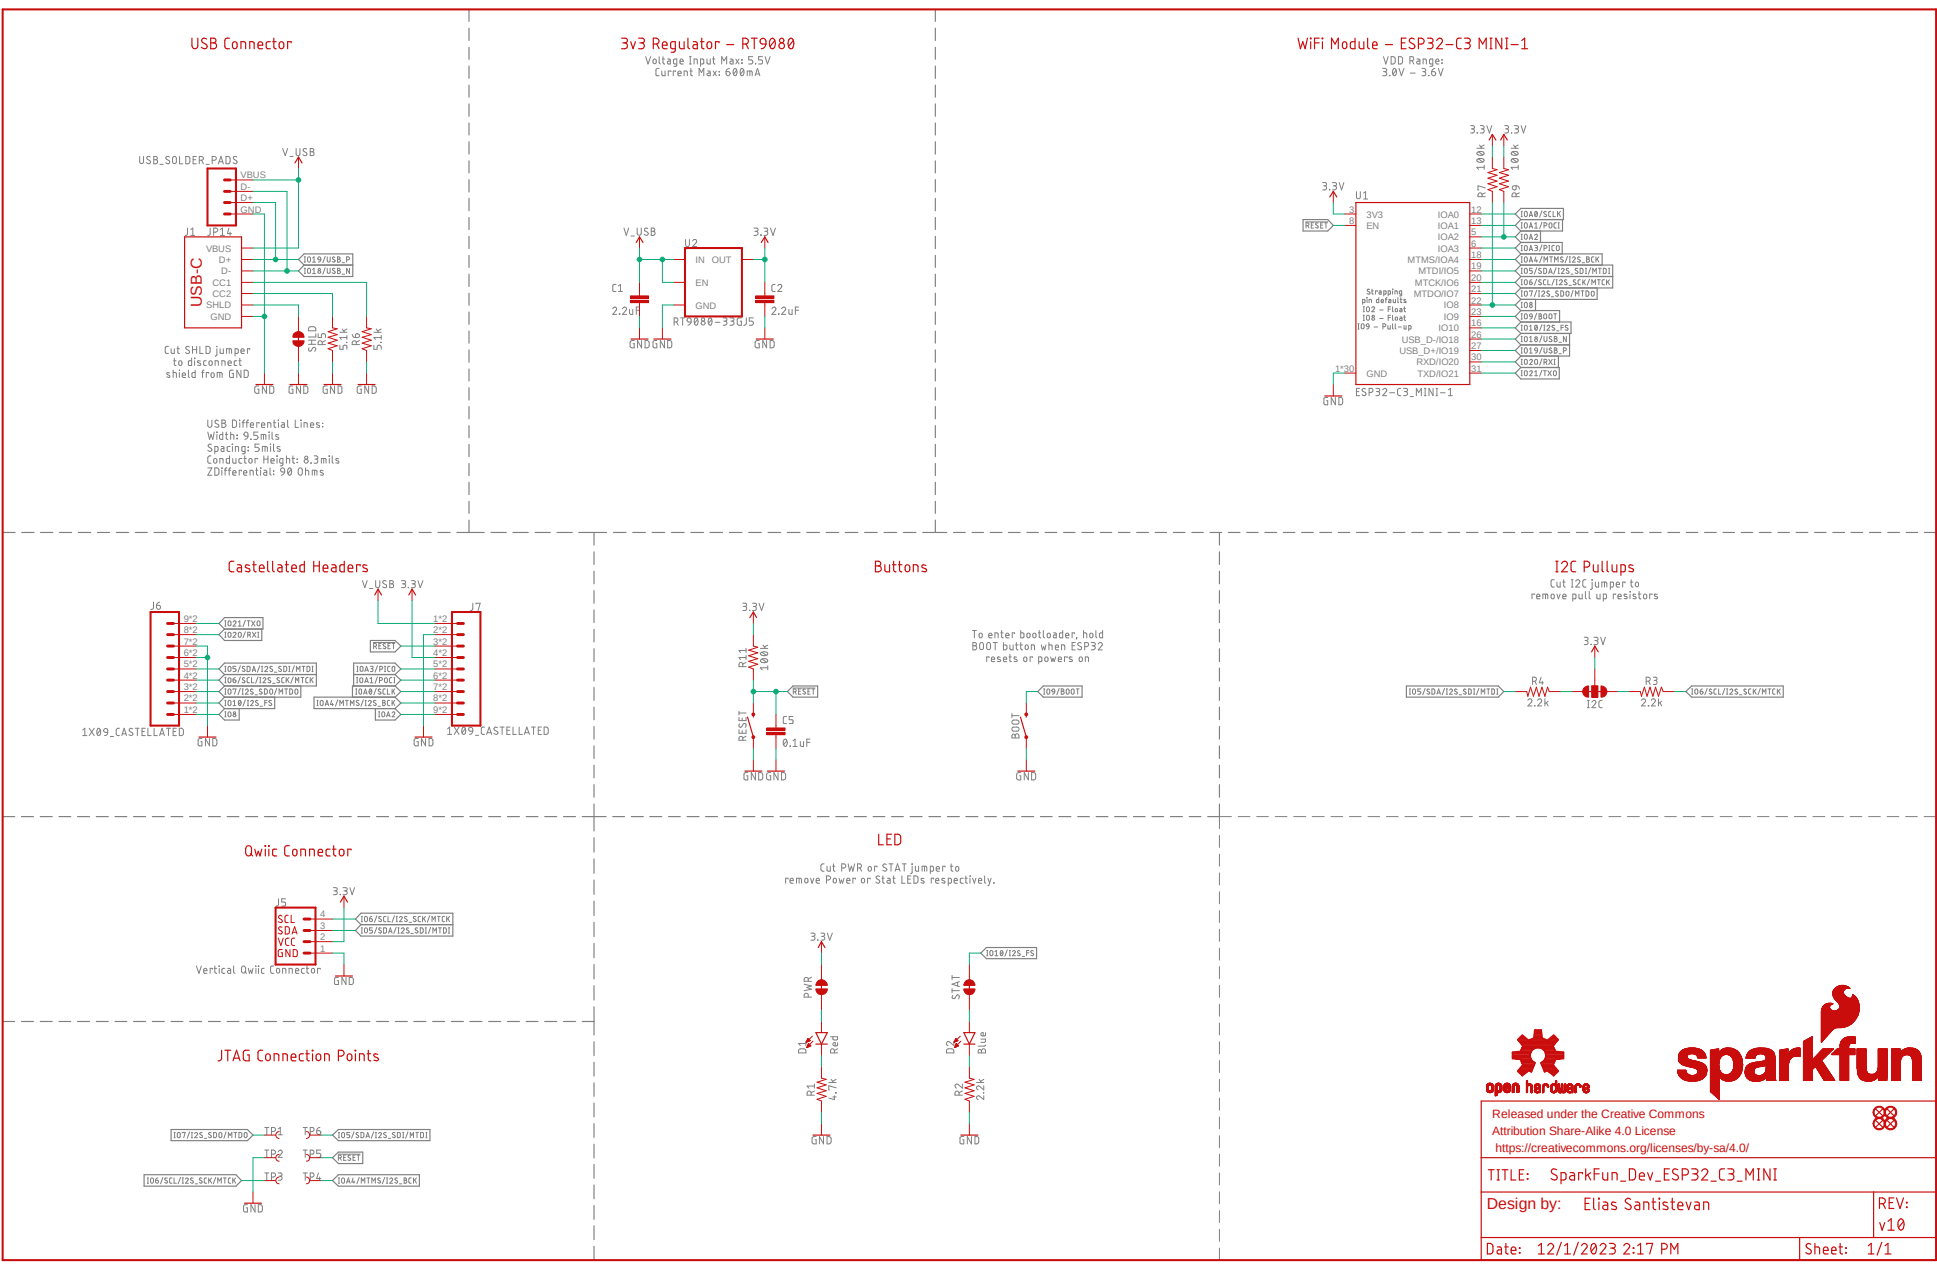
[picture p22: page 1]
GND; INGNDOUT EN; VBUS D- D+GND; GND 1*30; IOA0 12 IOA1 13 EN 8; IO8 22 IO9 23 USB_D-/IO18 26 USB_D+/IO19 27 RXD/IO20 30 TXD/IO21 31; IO10 16 USB⁻C; Design by:

IOA2 5
IOA3 6 MTMS/IOA4 18 MTDI/IO5 19 MTCK/IO6 20 MTDO/IO7 21

Released under the Creative Commons Attribution Share-Alike 4.0 License

https://creativecommons.org/licenses/by-sa/4.0/

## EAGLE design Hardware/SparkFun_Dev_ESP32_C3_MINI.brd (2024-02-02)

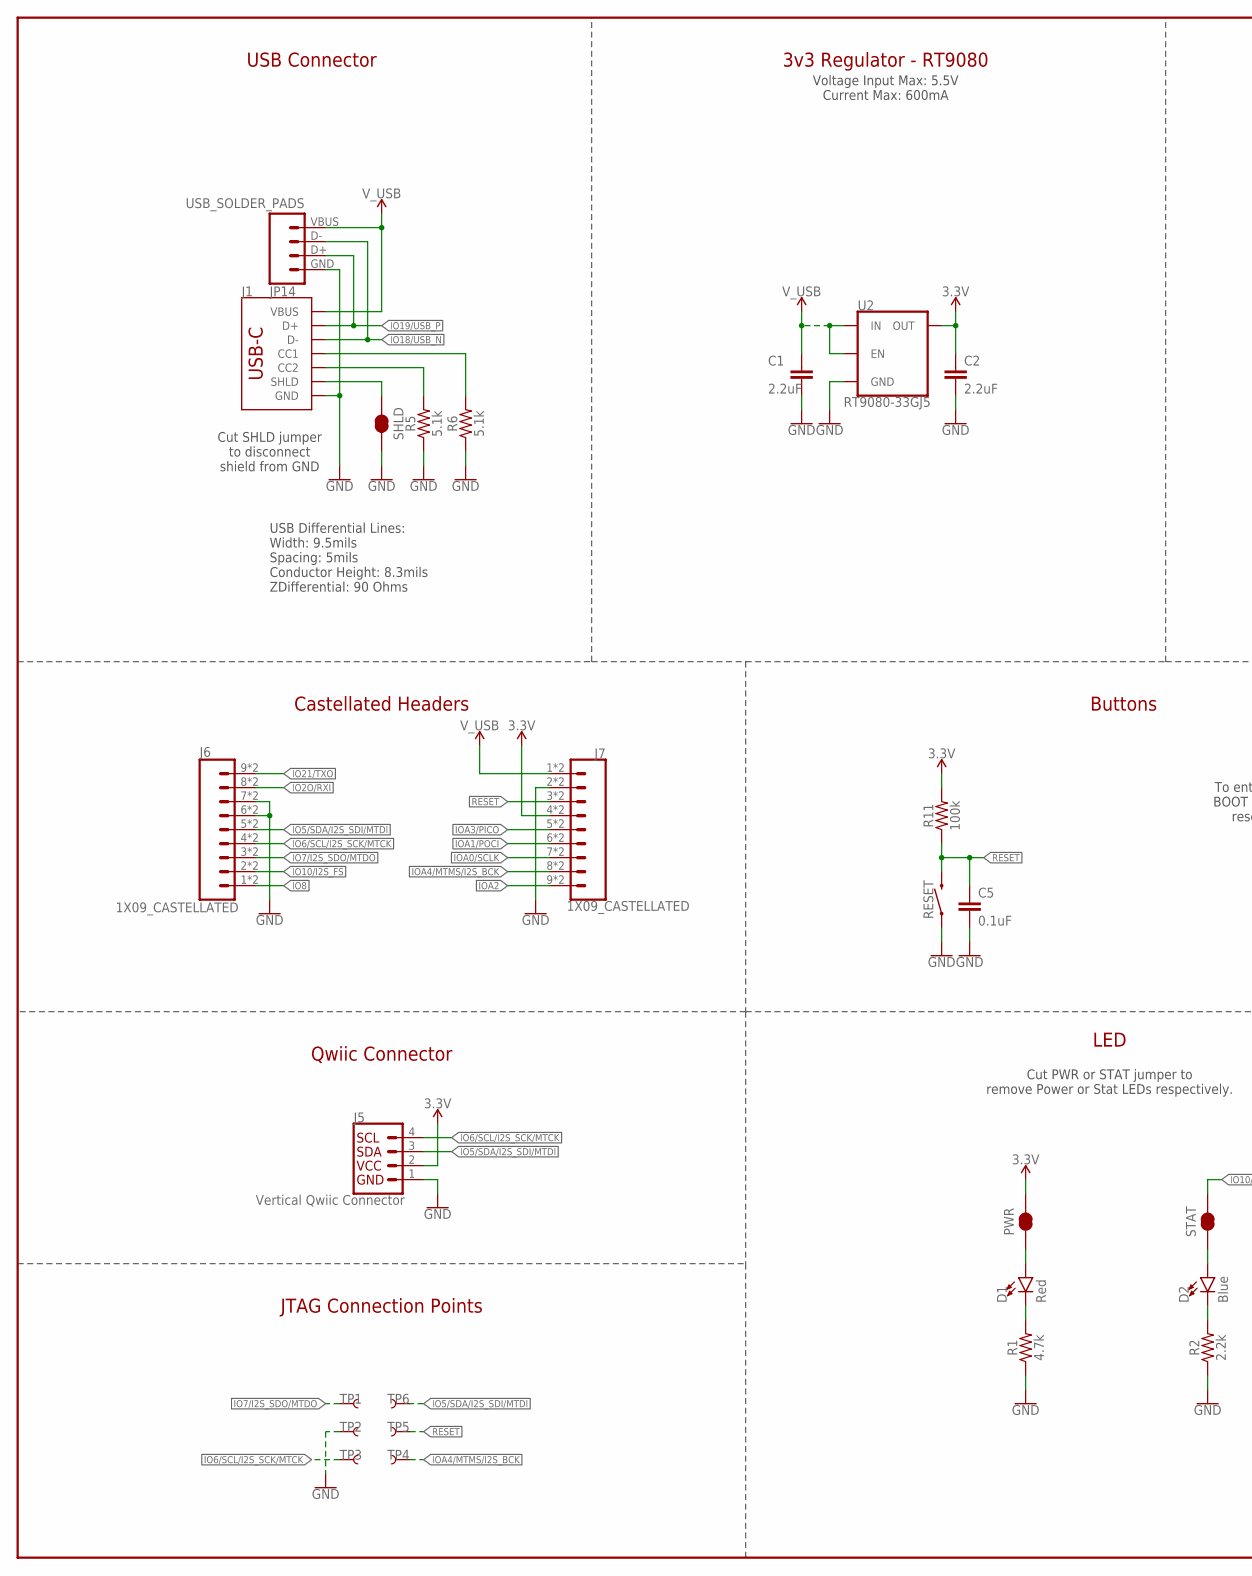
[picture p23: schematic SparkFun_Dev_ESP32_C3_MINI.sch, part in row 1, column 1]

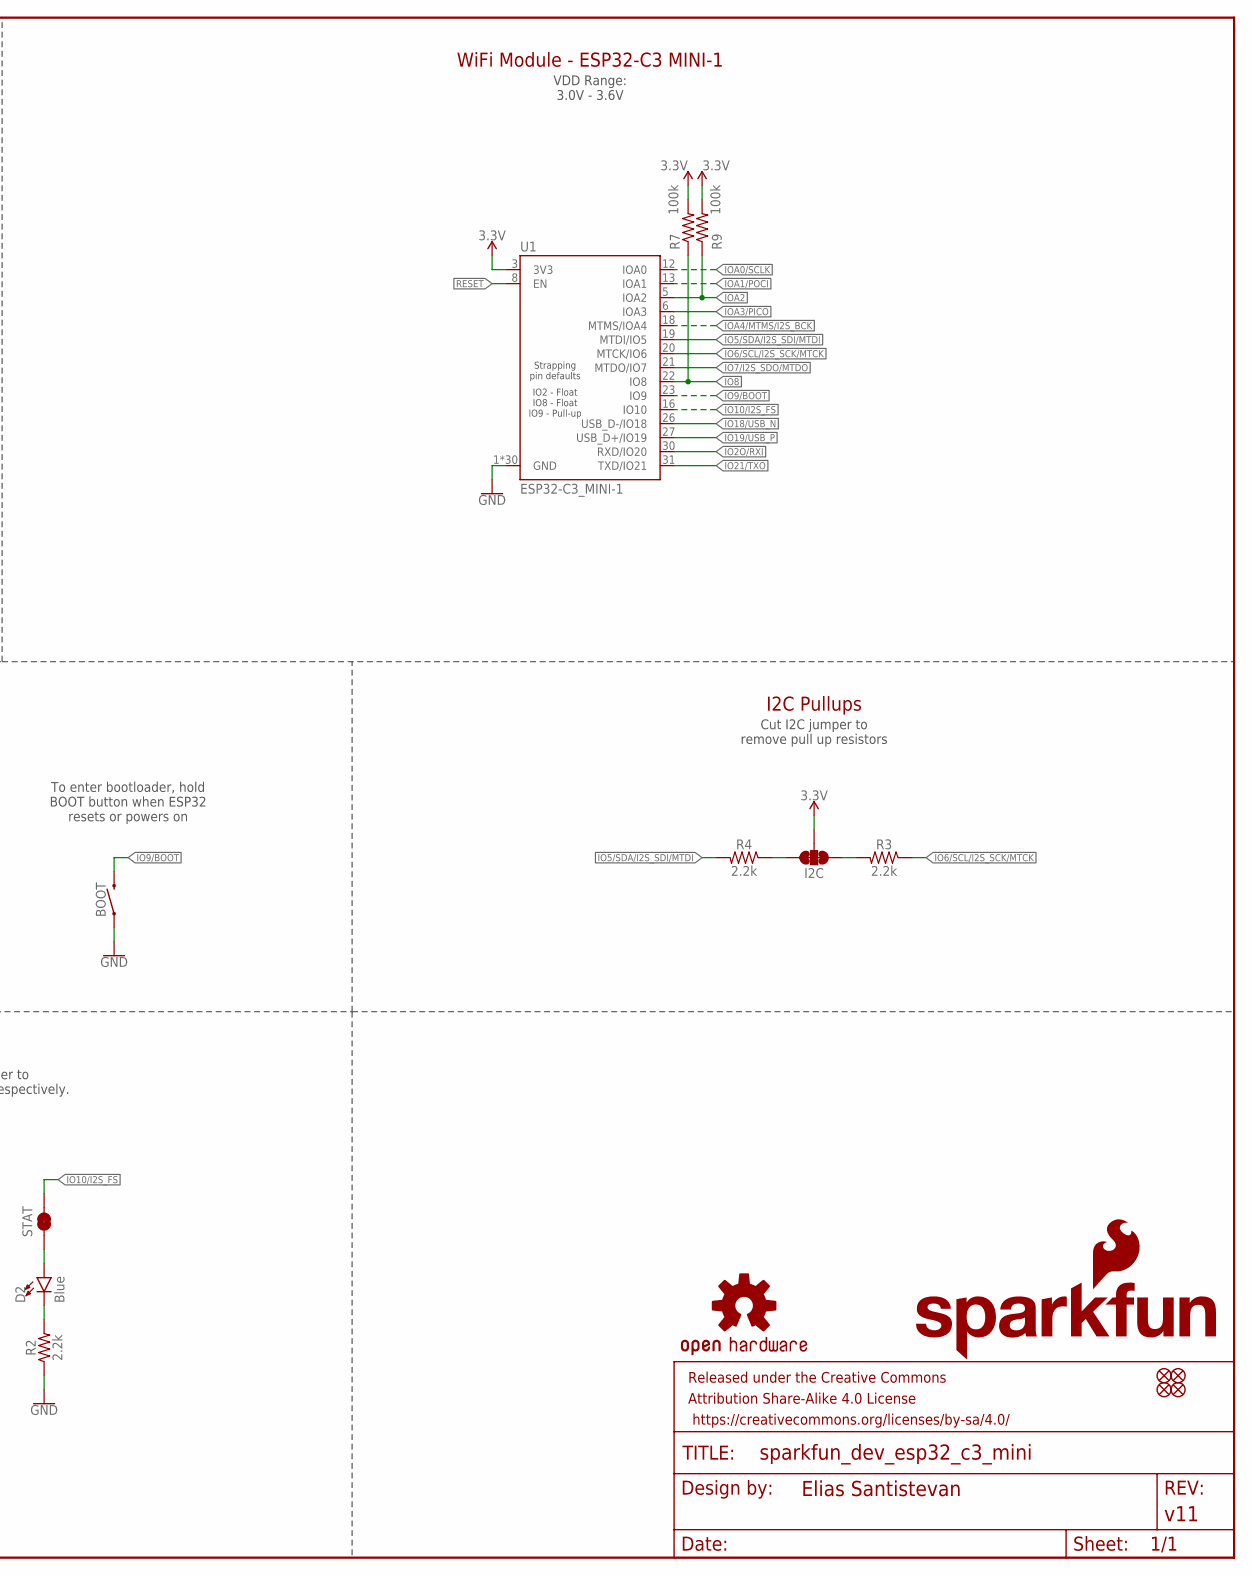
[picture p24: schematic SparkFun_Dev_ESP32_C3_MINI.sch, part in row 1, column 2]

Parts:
BOOT: MOMENTARY-SWITCH-SPST-SMD-4.6X2.8MM; TACTILE_SWITCH_SMD_4.6X2.8MM
C1, C2: 2.2uF; 0402-TIGHT
C5: 0.1uF; 0402-TIGHT
D1: Red; LED-0603
D2: Blue; LED-0603
FD1, FD2, FD3, FD4: FIDUCIALUFIDUCIAL; FIDUCIAL-MICRO
FRAME2: FRAME-LEDGER; CREATIVE_COMMONS
I2C: JUMPER-SMT_3_2-NC_TRACE_SILK; SMT-JUMPER_3_2-NC_TRACE_SILK
J1: USB Female Type C Connector; USB-C-16P_4LAYER-PADS
J5: Vertical Qwiic Connector; JST04_1MM_VERT
J6, J7: 1X09_CASTELLATED
JP14: USB_SOLDER_PADS; USB-SOLDER-PADS
LOGO1: SFE_LOGO_NAME_FLAMEBLANK; BLANK
LOGO3: OSHW-LOGOS; OSHW-LOGO-S
PWR: JUMPER-SMT_2_NC_TRACE_SILK; SMT-JUMPER_2_NC_TRACE_SILK
R1: 4.7k; 0402-TIGHT
R2, R3, R4: 2.2k; 0402-TIGHT
R5, R6: 5.1k; 0402-TIGHT
R7, R9, R11: 100k; 0402-TIGHT
RESET: MOMENTARY-SWITCH-SPST-SMD-4.6X2.8MM; TACTILE_SWITCH_SMD_4.6X2.8MM
SHLD: JUMPER-SMT_2_NC_TRACE_SILK; SMT-JUMPER_2_NC_TRACE_SILK
STAT: JUMPER-SMT_2_NC_TRACE_SILK; SMT-JUMPER_2_NC_TRACE_SILK
TP1, TP2, TP3, TP4, TP5, TP6: TEST-POINT3X5; PAD.03X.05
U1: ESP32-C3_MINI-1; ESP32-C3-MINI-1
U2: RT9080-33GJ5; SOT23-5

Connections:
3.3V: C2.1, I2C.2, J5.2, J7.4, J7.4B (4), PWR.2, R7.2, R9.2, R11.2, U1.3 (3V3), U2.5 (OUT)
!RESET!: C5.1, J7.3, J7.3B (3), R11.1, RESET.3 (2), RESET.4 (2), TP5.1, U1.8 (EN)
GND: BOOT.1, BOOT.2 (1), C1.2, C2.2, C5.2, J1.GND, J1.GND2 (GND), J5.1, J6.6, J6.6B (6), J6.7, J6.7B (7), J7.2, J7.2B (2), JP14.GND (4), R1.1, R2.1, R5.1, R6.1, RESET.1, RESET.2 (1), SHLD.2, TP2.1, U1.1 (GND), U1.2 (GND), U1.11 (GND), U1.14 (GND), U1.36 (GND), U1.37 (GND), U1.38 (GND), U1.39 (GND), U1.40 (GND), U1.41 (GND), U1.42 (GND), U1.43 (GND), U1.44 (GND), U1.45 (GND), U1.46 (GND), U1.47 (GND), U1.48 (GND), U1.49.1 (GND), U1.49.2 (GND), U1.49.3 (GND), U1.49.4 (GND), U1.49.5 (GND), U1.49.6 (GND), U1.49.7 (GND), U1.49.8 (GND), U1.49.9 (GND), U1.50 (GND), U1.51 (GND), U1.52 (GND), U1.53 (GND), U2.2 (GND)
IO2O/RXI: J6.8, J6.8B (8), U1.30 (RXD/IO20)
IO5/SDA/I2S_SDI/MTDI: J5.3, J6.5, J6.5B (5), R4.2, TP6.1, U1.19 (MTDI/IO5)
IO6/SCL/I2S_SCK/MTCK: J5.4, J6.4, J6.4B (4), R3.1, TP3.1, U1.20 (MTCK/IO6)
IO7/I2S_SDO/MTDO: J6.3, J6.3B (3), TP1.1, U1.21 (MTDO/IO7)
IO8: J6.1, J6.1B (1), R7.1, U1.22 (IO8)
IO9/BOOT: BOOT.3 (2), BOOT.4 (2), U1.23 (IO9)
IO10/I2S_FS: J6.2, J6.2B (2), STAT.2, U1.16 (IO10)
IO18/USB_N: J1.A7 (D-), J1.B7 (D-), JP14.D- (2), U1.26 (USB_D-/IO18)
IO19/USB_P: J1.A6 (D+), J1.B6 (D+), JP14.D+ (3), U1.27 (USB_D+/IO19)
IO21/TXO: J6.9, J6.9B (9), U1.31 (TXD/IO21)
IOA0/SCLK: J7.7, J7.7B (7), U1.12 (IOA0)
IOA1/POCI: J7.6, J7.6B (6), U1.13 (IOA1)
IOA2: J7.9, J7.9B (9), R9.1, U1.5 (IOA2)
IOA3/PICO: J7.5, J7.5B (5), U1.6 (IOA3)
IOA4/MTMS/I2S_BCK: J7.8, J7.8B (8), TP4.1, U1.18 (MTMS/IOA4)
unnamed: D1.C, R1.2
unnamed: D1.A, PWR.1
unnamed: D2.C, R2.2
unnamed: I2C.3, R3.2
unnamed: I2C.1, R4.1
unnamed: J1.B5 (CC2), R5.2
unnamed: J1.A5 (CC1), R6.2
unnamed: D2.A, STAT.1
SHLD: J1.SHLD1 (SHLD), J1.SHLD2 (SHLD), J1.SHLD3 (SHLD), J1.SHLD4 (SHLD), SHLD.1
V_USB: C1.1, J1.VBUS1 (VBUS), J1.VBUS2 (VBUS), J7.1, J7.1B (1), JP14.VBUS (1), U2.1 (IN), U2.3 (EN)

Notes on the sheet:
USB Connector
3v3 Regulator - RT9080
Qwiic Connector
Castellated Headers
LED
Buttons
I2C Pullups
WiFi Module - ESP32-C3 MINI-1
VDD Range: 3.0V - 3.6V
Cut I2C jumper to remove pull up resistors
Cut PWR or STAT jumper to remove Power or Stat LEDs respectively.
Voltage Input Max: 5.5V Current Max: 600mA
To enter bootloader, hold BOOT button when ESP32 resets or powers on
Cut SHLD jumper to disconnect shield from GND
JTAG Connection Points
USB Differential Lines: Width: 9.5mils Spacing: 5mils Conductor Height: 8.3mils ZDifferential: 90 Ohms

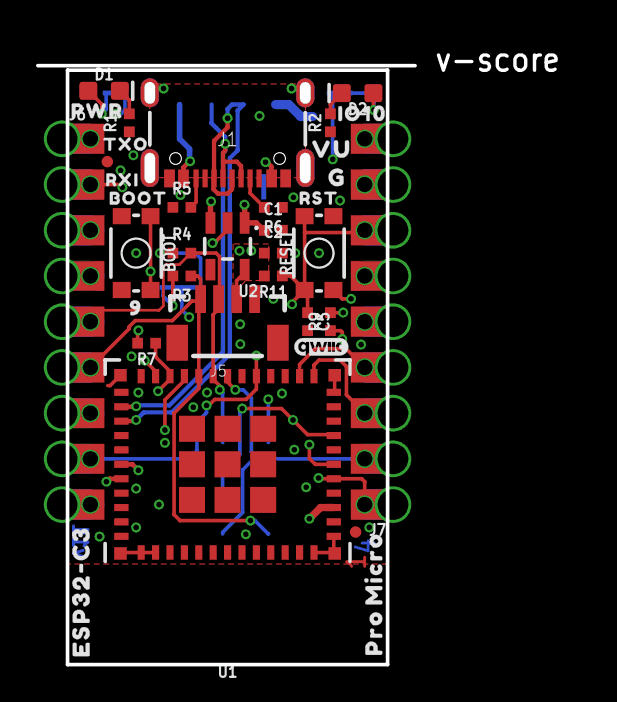
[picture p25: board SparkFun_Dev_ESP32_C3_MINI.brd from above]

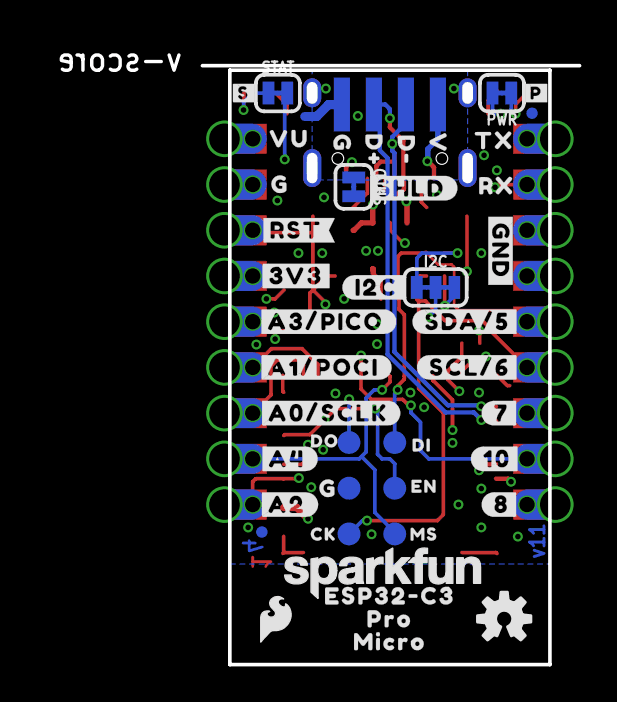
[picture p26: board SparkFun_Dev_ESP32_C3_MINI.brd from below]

Board: 4 copper layers, 17.8 x 33.0 mm, 90 parts (50 on the bottom side), 28 nets.

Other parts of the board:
U$1, U$31, U$33, U$39: G36
U$2: IO1044
U$3: 93
U$4: #3V3#0
U$5: RST41
U$6: #I2C#947
U$7: #P#49
U$8: #S#51
U$9: #RST#945
U$10, U$51: VU35
U$11: #SHLD#946
U$12: #8#50
U$13: #A1#POCI#50
U$14: #A0#SCLK#50
U$15: #A4#50
U$16: #A2#50
U$17: TX40
U$18: SFE_LOGO_NAME_.1
U$20: #7#50
U$21: #10#50
U$22: #GND#4
U$23: CK39
U$24: ORDERING_INSTRUCTIONS
U$25: D#33
U$26: D#34
U$27: DI36
U$28: DO35
U$29: EN37
U$30: MS38
U$32: V35
U$34, U$45: ESP32#C32
U$35, U$46: PRO0
U$36, U$47: MICRO1
U$37: RX39
U$40: #A3#PICO#45
U$41: BOOT15
U$42: RXI39
U$43: TXO40
U$44: #SDA#5#10952
U$48: SFE_LOGO_FLAME_.1
U$49: PWR945
U$50: QWIIC_3MM
U$53: #SCL#6#10952

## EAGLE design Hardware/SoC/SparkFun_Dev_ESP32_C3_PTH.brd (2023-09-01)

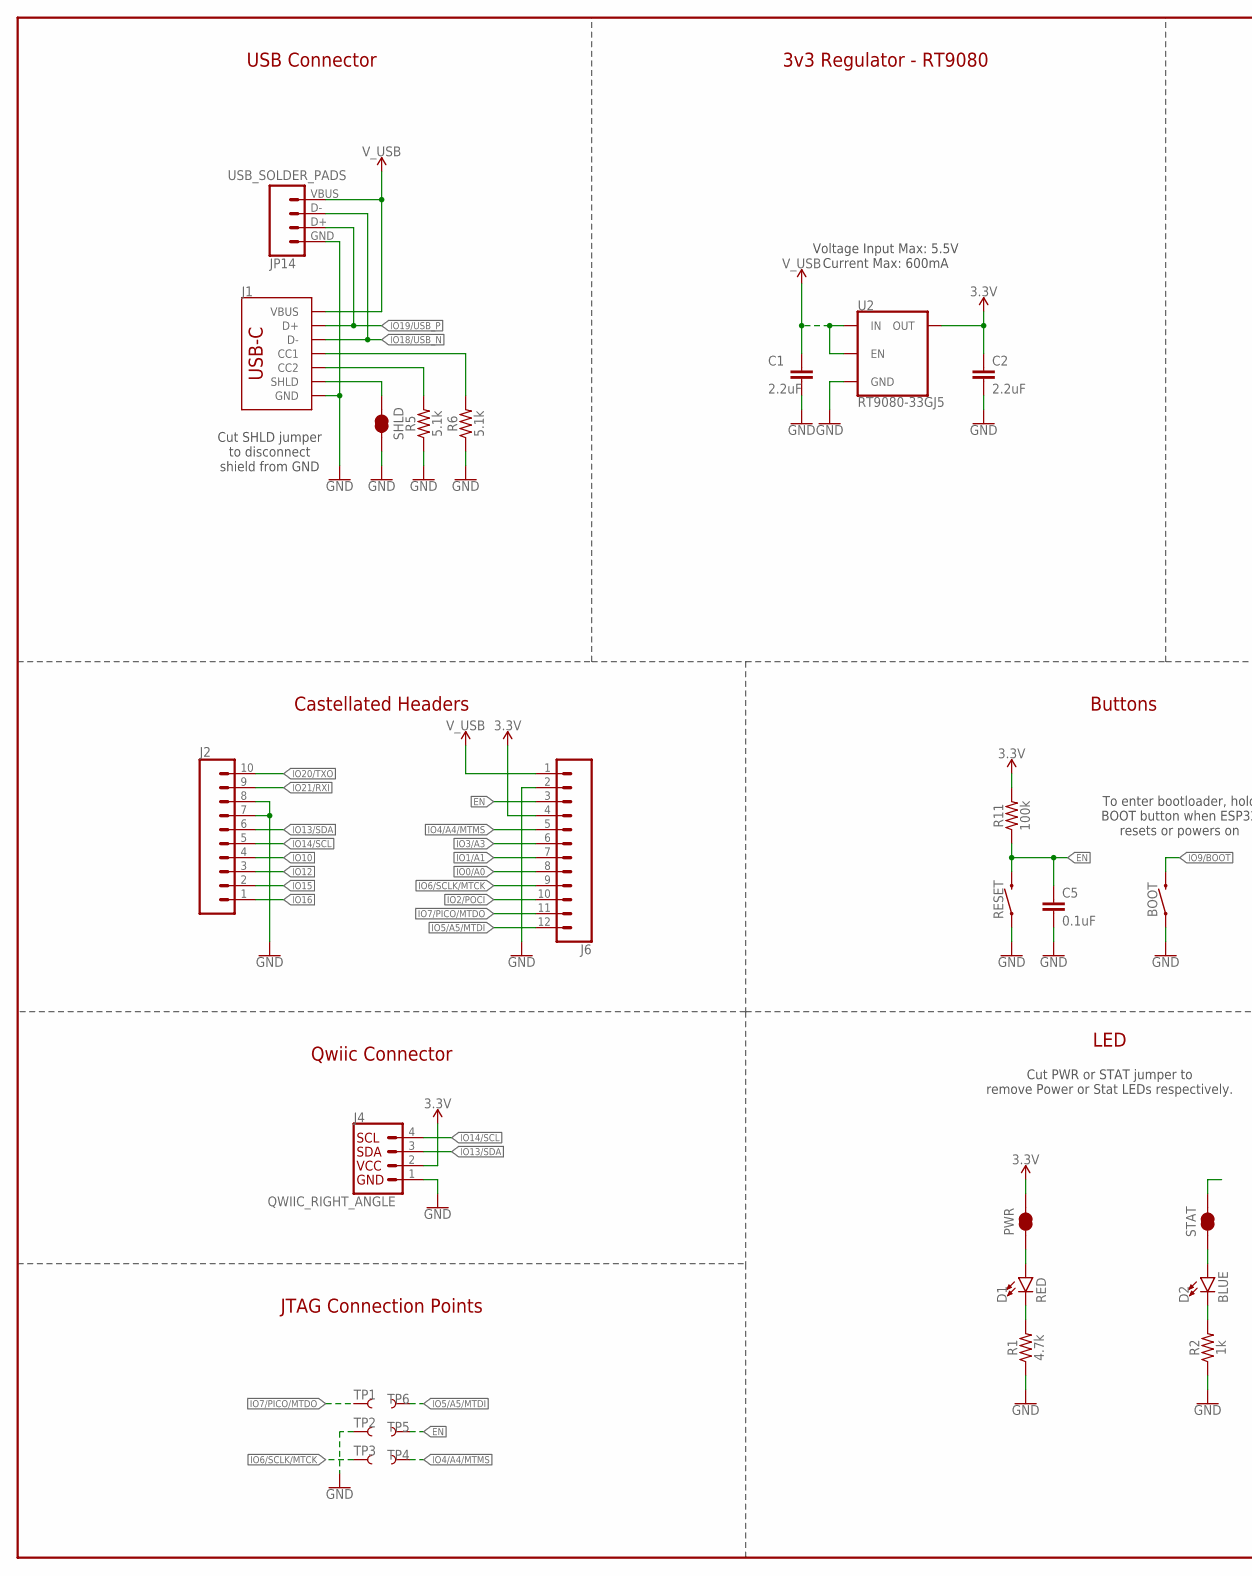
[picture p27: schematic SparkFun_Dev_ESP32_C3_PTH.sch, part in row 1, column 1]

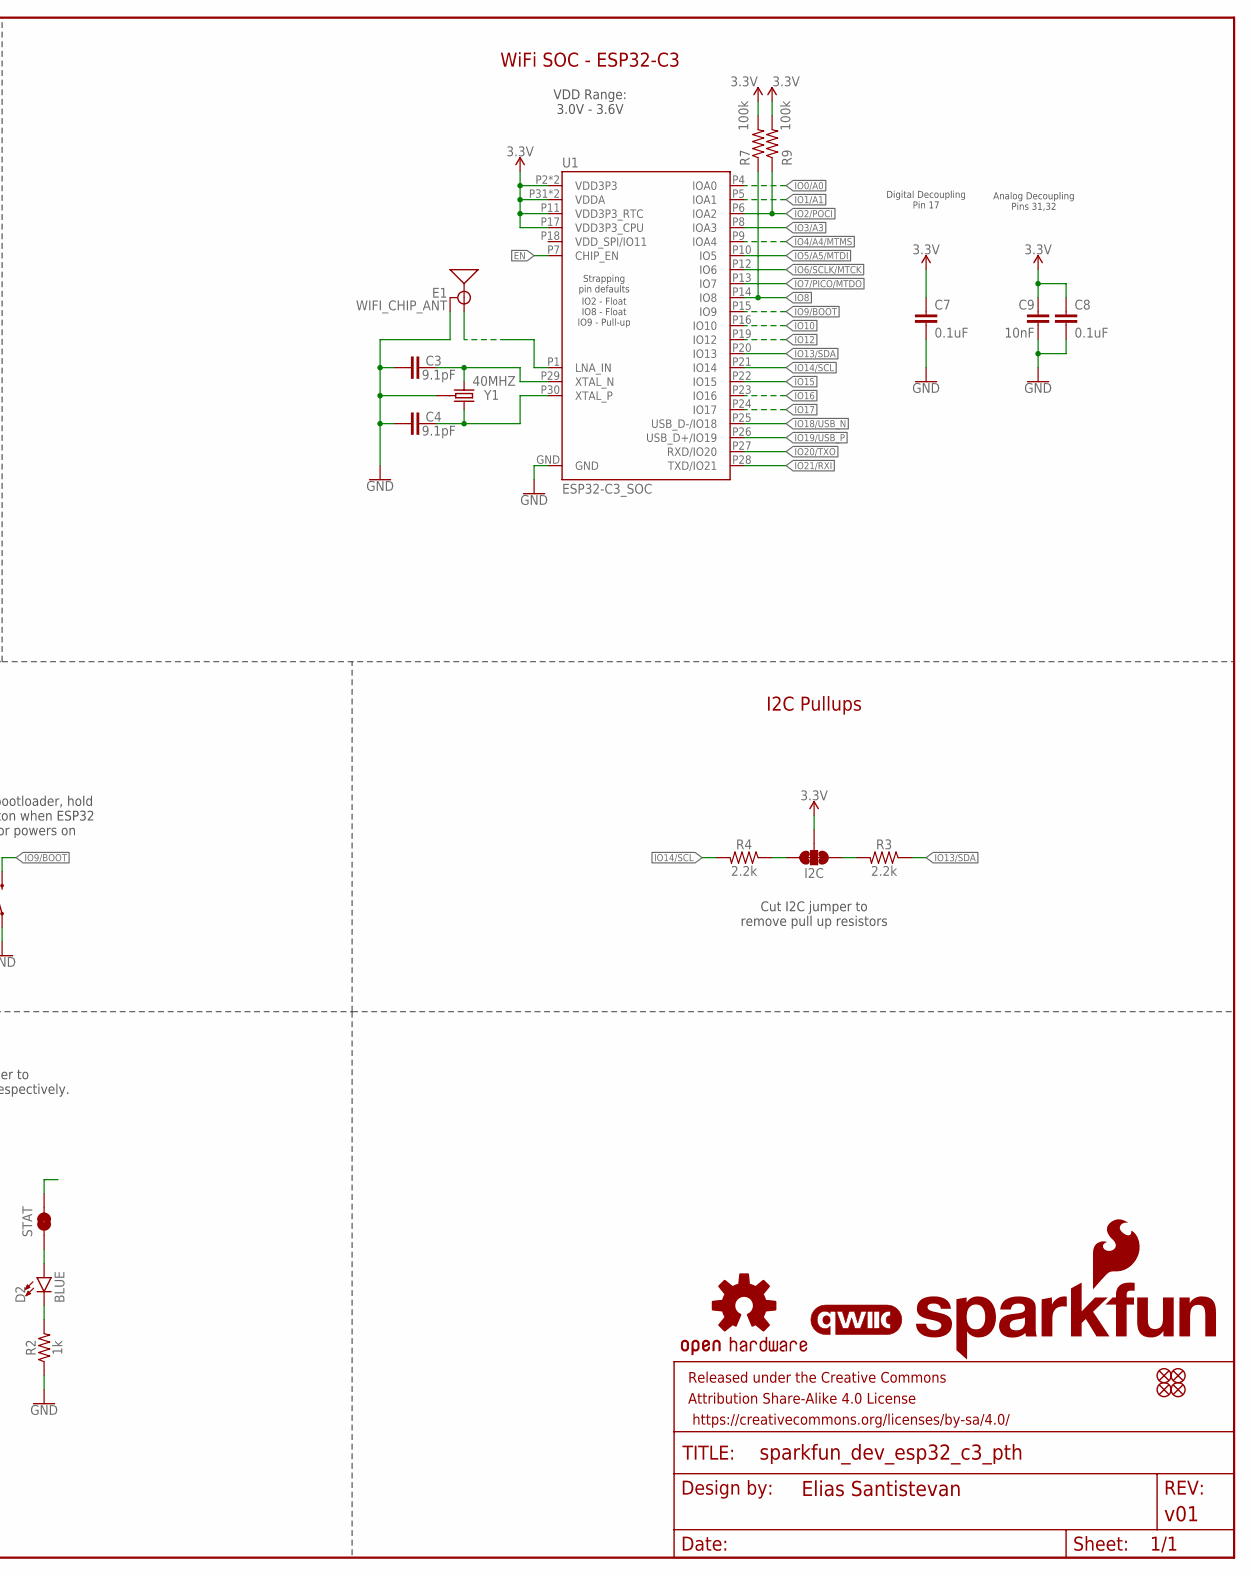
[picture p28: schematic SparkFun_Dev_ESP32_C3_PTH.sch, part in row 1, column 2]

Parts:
BOOT: MOMENTARY-SWITCH-SPST-SMD-4.6X2.8MM; TACTILE_SWITCH_SMD_4.6X2.8MM
C1, C2: 2.2uF; 0402-TIGHT
C3, C4: 9.1pF; 0402-TIGHT
C5, C7, C8: 0.1uF; 0402-TIGHT
C9: 10nF; 0402-TIGHT
D1: RED; LED-0603
D2: BLUE; LED-0603
E1: WIFI_CHIP_ANT; CHIP_ANT_NO_COURTYARD
FD1, FD2, FD3, FD4: FIDUCIALUFIDUCIAL; FIDUCIAL-MICRO
FRAME2: FRAME-LEDGER; CREATIVE_COMMONS
I2C: JUMPER-SMT_3_2-NC_TRACE_SILK; SMT-JUMPER_3_2-NC_TRACE_SILK
J1: USB Female Type C Connector; USB-C-16P_4LAYER-PADS
J2: CONN_10NO_SILK_PTH_FEMALE; 1X10_NO_SILK
J4: QWIIC_RIGHT_ANGLE; JST04_1MM_RA
J6: CONN_121X12_NO_SILK_KIT; 1X12_NO_SILK_KIT
JP14: USB_SOLDER_PADS; USB-SOLDER-PADS
LOGO1: SFE_LOGO_NAME_FLAMEBLANK; BLANK
LOGO2: QWIIC_LOGO_3MM; QWIIC_3MM
LOGO3: OSHW-LOGOS; OSHW-LOGO-S
PWR: JUMPER-SMT_2_NC_TRACE_SILK; SMT-JUMPER_2_NC_TRACE_SILK
R1: 4.7k; 0402-TIGHT
R2: 1k; 0402-TIGHT
R3, R4: 2.2k; 0402-TIGHT
R5, R6: 5.1k; 0402-TIGHT
R7, R9, R11: 100k; 0402-TIGHT
RESET: MOMENTARY-SWITCH-SPST-SMD-4.6X2.8MM; TACTILE_SWITCH_SMD_4.6X2.8MM
SHLD: JUMPER-SMT_2_NC_TRACE_SILK; SMT-JUMPER_2_NC_TRACE_SILK
STAT: JUMPER-SMT_2_NC_TRACE_SILK; SMT-JUMPER_2_NC_TRACE_SILK
TP1, TP2, TP3, TP4, TP5, TP6: TEST-POINT3X5; PAD.03X.05
U1: ESP32-C3_SOC; QFN32
U2: RT9080-33GJ5; SOT23-5
Y1: 40MHZ; CRYSTAL-SMD-2X2.5MM

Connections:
3.3V: C2.1, C7.1, C8.1, C9.1, I2C.2, J4.2, J6.4, PWR.2, R7.2, R9.2, R11.2, U1.P2 (VDD3P3), U1.P3 (VDD3P3), U1.P11 (VDD3P3_RTC), U1.P17 (VDD3P3_CPU), U1.P31 (VDDA), U1.P32 (VDDA), U2.5 (OUT)
ANT: E1.P1 (SIGNAL), U1.P1 (LNA_IN)
EN: C5.1, J6.3, R11.1, RESET.3 (2), RESET.4 (2), TP5.1, U1.P7 (CHIP_EN)
GND: BOOT.1, BOOT.2 (1), C1.2, C2.2, C3.1, C4.1, C5.2, C7.2, C8.2, C9.2, E1.P3 (GND), E1.P4 (GND), J1.GND, J1.GND2 (GND), J2.7, J2.8, J4.1, J6.2, JP14.GND (4), R1.1, R2.1, R5.1, R6.1, RESET.1, RESET.2 (1), SHLD.2, TP2.1, U1.GND, U2.2 (GND), Y1.P2 (GND), Y1.P4 (GND)
IO0/A0: J6.8, U1.P4 (IOA0)
IO1/A1: J6.7, U1.P5 (IOA1)
IO2/POCI: J6.10, R9.1, U1.P6 (IOA2)
IO3/A3: J6.6, U1.P8 (IOA3)
IO4/A4/MTMS: J6.5, TP4.1, U1.P9 (IOA4)
IO5/A5/MTDI: J6.12, TP6.1, U1.P10 (IO5)
IO6/SCLK/MTCK: J6.9, TP3.1, U1.P12 (IO6)
IO7/PICO/MTDO: J6.11, TP1.1, U1.P13 (IO7)
IO8: R7.1, U1.P14 (IO8)
IO9/BOOT: BOOT.3 (2), BOOT.4 (2), U1.P15 (IO9)
IO10: J2.4, U1.P16 (IO10)
IO12: J2.3, U1.P19 (IO12)
IO13/SDA: J2.6, J4.3, R3.1, U1.P20 (IO13)
IO14/SCL: J2.5, J4.4, R4.2, U1.P21 (IO14)
IO15: J2.2, U1.P22 (IO15)
IO16: J2.1, U1.P23 (IO16)
IO17: U1.P24 (IO17)
IO18/USB_N: J1.A7 (D-), J1.B7 (D-), JP14.D- (2), U1.P25 (USB_D-/IO18)
IO19/USB_P: J1.A6 (D+), J1.B6 (D+), JP14.D+ (3), U1.P26 (USB_D+/IO19)
IO20/TXO: J2.10, U1.P27 (RXD/IO20)
IO21/RXI: J2.9, U1.P28 (TXD/IO21)
unnamed: D1.C, R1.2
unnamed: D1.A, PWR.1
unnamed: D2.C, R2.2
unnamed: I2C.3, R3.2
unnamed: I2C.1, R4.1
unnamed: J1.B5 (CC2), R5.2
unnamed: J1.A5 (CC1), R6.2
unnamed: C3.2, U1.P29 (XTAL_N), Y1.P1 (1)
unnamed: C4.2, U1.P30 (XTAL_P), Y1.P3 (2)
unnamed: D2.A, STAT.1
SHLD: J1.SHLD1 (SHLD), J1.SHLD2 (SHLD), J1.SHLD3 (SHLD), J1.SHLD4 (SHLD), SHLD.1
V_USB: C1.1, J1.VBUS1 (VBUS), J1.VBUS2 (VBUS), J6.1, JP14.VBUS (1), U2.1 (IN), U2.3 (EN)

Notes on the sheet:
USB Connector
3v3 Regulator - RT9080
Qwiic Connector
Castellated Headers
LED
Buttons
I2C Pullups
WiFi SOC - ESP32-C3
VDD Range: 3.0V - 3.6V
Cut I2C jumper to remove pull up resistors
Cut PWR or STAT jumper to remove Power or Stat LEDs respectively.
Voltage Input Max: 5.5V Current Max: 600mA
To enter bootloader, hold BOOT button when ESP32 resets or powers on
Cut SHLD jumper to disconnect shield from GND
Analog Decoupling Pins 31,32
Digital Decoupling Pin 17
JTAG Connection Points

Board: 4 copper layers, 49 parts (15 on the bottom side), 36 nets, no tracks yet.

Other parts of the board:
U$24: ORDERING_INSTRUCTIONS

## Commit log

2023-08-14 Adds datasheet, adds footprint, starts design
    [SparkFun_Dev_ESP32_C3.brd, SparkFun_Dev_ESP32_C3.sch]
2023-08-14 Shrinks design
    [SparkFun_Dev_ESP32_C3.brd, SparkFun_Dev_ESP32_C3.sch]
2023-08-15 Adds crystal
    [SparkFun_Dev_ESP32_C3.brd, SparkFun_Dev_ESP32_C3.sch]
2023-08-17 Adds more documentation, decoupling caps, antennas, rearranges schematic
    [SparkFun_Dev_ESP32_C3.brd, SparkFun_Dev_ESP32_C3.sch]
2023-08-23 Adds new antenna, nets IO, removes STAT LED
    [SparkFun_Dev_ESP32_C3.brd, SparkFun_Dev_ESP32_C3.sch]
2023-08-25 Moves towards Pro Micro form factor
    [SparkFun_Dev_ESP32_C3.brd, SparkFun_Dev_ESP32_C3.sch]
2023-08-25 Moves the parts into position
    [SparkFun_Dev_ESP32_C3.brd, SparkFun_Dev_ESP32_C3.sch]
2023-08-28 Fixes schematic
    [SparkFun_Dev_ESP32_C3.brd, SparkFun_Dev_ESP32_C3.sch]
2023-08-28 More I/O netting from ESP32C3 to headers
    [SparkFun_Dev_ESP32_C3.brd, SparkFun_Dev_ESP32_C3.sch]
2023-08-28 Adds JTAG header and corrects boot control configuration
    [SparkFun_Dev_ESP32_C3.brd, SparkFun_Dev_ESP32_C3.sch]
2023-08-29 Moves any connections away from antenna
    * Finishes netting
    [SparkFun_Dev_ESP32_C3.brd, SparkFun_Dev_ESP32_C3.sch]
2023-08-29 Updates thickness in ordering instructions
    [SparkFun_Dev_ESP32_C3.brd]
2023-08-31 Adds MINI module, creates new design with MINI module netted
    [SparkFun_Dev_ESP32_C3.brd, SparkFun_Dev_ESP32_C3.sch, SparkFun_Dev_ESP32_C3_MINI.brd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]
2023-08-31 Moves some parts away as lost in thought
    [SparkFun_Dev_ESP32_C3_MINI.brd]
2023-08-31 Moves around some capacitors
    [SparkFun_Dev_ESP32_C3_MINI.brd]
2023-08-31 Adds PTH version
    [SparkFun_Dev_ESP32_C3_MINI - PTH.brd, SparkFun_Dev_ESP32_C3_MINI - PTH.sch]
2023-09-01 Adds 9 pin connector to the MINI designs
    [SparkFun_Dev_ESP32_C3_MINI - PTH.brd, SparkFun_Dev_ESP32_C3_MINI - PTH.sch, SparkFun_Dev_ESP32_C3_MINI.brd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]
2023-09-01 Fixes symbol for ESP32 SOC, adds a few more headers, adds new SOC PTH design
    [SparkFun_Dev_ESP32_C3_PTH.brd, SparkFun_Dev_ESP32_C3_PTH.sch]
2023-09-01 Moves unused board files to "OLD"
    [SparkFun_Dev_ESP32_C3.brd, SparkFun_Dev_ESP32_C3.sch, SparkFun_Dev_ESP32_C3_MINI - PTH.brd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]
2023-09-01 Some updates to layout
    [SparkFun_Dev_ESP32_C3_MINI.brd]
2023-09-01 Removes unnecessary documents, , moves boar daround
    [SparkFun_Dev_ESP32_C3_MINI.brd, SparkFun_Dev_ESP32_C3_MINI.sch]
2023-09-01 Fixes net names that were blasted away
    [SparkFun_Dev_ESP32_C3_MINI.brd, SparkFun_Dev_ESP32_C3_MINI.sch]
2023-09-01 Adds I2S nets, we'll see
    [SparkFun_Dev_ESP32_C3_MINI.brd, SparkFun_Dev_ESP32_C3_MINI.sch]
2023-09-01 Adds new C3 module so that the device value is correct
    * Fixes testpoints
    [SparkFun_Dev_ESP32_C3_MINI.brd, SparkFun_Dev_ESP32_C3_MINI.sch]
2023-09-01 Moves stat LED
    [SparkFun_Dev_ESP32_C3_MINI.brd, SparkFun_Dev_ESP32_C3_MINI.sch]
2023-09-01 Paranoid upload
    [SparkFun_Dev_ESP32_C3_MINI.brd]
2023-09-05 Routes some nets
    [SparkFun_Dev_ESP32_C3_MINI.brd, SparkFun_Dev_ESP32_C3_MINI.sch]
2023-09-05 Routes most signals (soppily)
    [SparkFun_Dev_ESP32_C3_MINI.brd]
2023-09-05 Routes EVEN MORE signals again, sloppily - no judgements
    [SparkFun_Dev_ESP32_C3_MINI.brd]
2023-09-05 Slight adjustment to TX
    [SparkFun_Dev_ESP32_C3_MINI.brd]
2023-09-06 Approves many many DRC errors generated by castellated leads
    [SparkFun_Dev_ESP32_C3_MINI.brd]
2023-09-06 Renames some nets for clarity, adds vias, cleans up ground pours, fixes air wires
    [SparkFun_Dev_ESP32_C3_MINI.brd, SparkFun_Dev_ESP32_C3_MINI.sch]
2023-09-06 Adds most of the silk on the bottom side
    [SparkFun_Dev_ESP32_C3_MINI.brd]
2023-09-07 Adds more silk, removes some shield polygons on inner layers
    * Moves fiducials around
    * Swaps I2C lines at PTH header
    [SparkFun_Dev_ESP32_C3_MINI.brd, SparkFun_Dev_ESP32_C3_MINI.sch]
2023-09-07 Adds measures
    [SparkFun_Dev_ESP32_C3_MINI.brd]
2023-09-07 Fixes UART lines at module
    [SparkFun_Dev_ESP32_C3_MINI.brd, SparkFun_Dev_ESP32_C3_MINI.sch]
2023-09-08 Updates symbol to include correct JTAG interface
    * Updates nets to reflect JTAG correction, moves JTAG header and routes new JTAG connection
    * Updates silk for fix above
    [SparkFun_Dev_ESP32_C3_MINI.brd, SparkFun_Dev_ESP32_C3_MINI.sch]
2023-09-11 Fixes castellation, adds removeable tab
    * Reduces minimum annular ring to 3mil
    * Adds silk to removeable tag
    * Changes "EN" silk to "RST"
    [SparkFun_Dev_ESP32_C3_MINI.brd, SparkFun_Dev_ESP32_C3_MINI.sch]
2023-09-11 Adds PROD ID to ESP32 module
    [SparkFun_Dev_ESP32_C3_MINI.brd, SparkFun_Dev_ESP32_C3_MINI.sch]
2023-09-11 Fixes various potential acid traps
    [SparkFun_Dev_ESP32_C3_MINI.brd]
2023-09-11 Adds a few vias, cams prototypes
    [SparkFun_Dev_ESP32_C3_MINI.GBL, SparkFun_Dev_ESP32_C3_MINI.GBO, SparkFun_Dev_ESP32_C3_MINI.GBP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]
2023-09-12 Shortens some nets, fixes some silk
    [SparkFun_Dev_ESP32_C3_MINI.brd, SparkFun_Dev_ESP32_C3_MINI.sch]
2023-10-18 renames board files
2023-10-19 Renames I2S pins
    [SparkFun_Dev_ESP32_C3_MINI.brd, SparkFun_Dev_ESP32_C3_MINI.sch]
2023-10-25 Adds numerous aesthetic changes
    * Increases size of silk everywhere possible
    * Moves jumpers for LEDs to the corners underneath the respective LED.
    [SparkFun_Dev_ESP32_C3_MINI.brd, SparkFun_Dev_ESP32_C3_MINI.sch]
2023-10-25 Adds more aesthetic changes
    * Note on previous commit: I2C labels were removed from silk
    * Fixes ground silk rectangle
    * rotates qwiic label
    * Shrinks VBUS polygon
    * Moves boot capacitor to other side of button
    [SparkFun_Dev_ESP32_C3_MINI.brd, SparkFun_Dev_ESP32_C3_MINI.sch]
2023-10-25 Fixes DRC issues
    * Moves shield jumper away from VUSB via
    [SparkFun_Dev_ESP32_C3_MINI.brd]
2023-10-26 Moves version onto the PCB, and rolls version in schematic
    [SparkFun_Dev_ESP32_C3_MINI.brd, SparkFun_Dev_ESP32_C3_MINI.sch]
2023-10-26 Fixes some acid traps, fixes some schematic odds and ends
    [SparkFun_Dev_ESP32_C3_MINI.brd, SparkFun_Dev_ESP32_C3_MINI.sch]
2023-10-30 Updates to silk, reorders some pin names on ESP32 symbol
    [SparkFun_Dev_ESP32_C3_MINI.brd, SparkFun_Dev_ESP32_C3_MINI.sch]
2023-10-30 Adds SparkFun logo
    [SparkFun_Dev_ESP32_C3_MINI.brd, SparkFun_Dev_ESP32_C3_MINI.sch]
2023-10-30 Updates USB lines to get it even closer to 90 Ohms
    [SparkFun_Dev_ESP32_C3_MINI.brd, SparkFun_Dev_ESP32_C3_MINI.sch]
2023-11-03 Adds gerbers for panel and note about castellated leads to ordering instructions
    [SparkFun_Dev_ESP32_C3_MINI.brd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]
2023-12-06 Updates silk, and rolls to v11
    [SparkFun_Dev_ESP32_C3_MINI.brd, SparkFun_Dev_ESP32_C3_MINI.sch]
2023-12-07 Small fix for ground pour
    [SparkFun_Dev_ESP32_C3_MINI.brd]
2023-12-07 Adds new panel
    [SparkFun_Dev_ESP32_C3_MINI-Panel.GBS, SparkFun_Dev_ESP32_C3_MINI-Panel.GKO, SparkFun_Dev_ESP32_C3_MINI-Panel.GTO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]
2024-01-15 Fixing Hardware Assembly
2024-01-16 Finishing hardware assembly and fixing gif rotation
2024-02-01 Updated Schematic and EagleFiles
2024-02-02 Puts board files into their own folder
2024-02-02 Removes old hardware files, removes old libraries, replaces parts in local library with parts now in SparkFun Eagle libraries
    [SparkFun_Dev_ESP32_C3.brd, SparkFun_Dev_ESP32_C3.sch, SparkFun_Dev_ESP32_C3_MINI - PTH.brd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]
2024-02-02 Renames boards.txt file to sparkfun_boards
2024-02-02 Adding instructions for esp32 board file installation
2024-02-05 Rename pins_arduino.h to pins_arduino.h
    Fixes camel case in variant folder name

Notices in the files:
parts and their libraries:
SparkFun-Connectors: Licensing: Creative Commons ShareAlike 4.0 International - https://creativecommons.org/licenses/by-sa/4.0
